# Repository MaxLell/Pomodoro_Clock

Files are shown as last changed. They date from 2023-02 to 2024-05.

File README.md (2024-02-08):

# Pomodoro_Clock

## Why?
This device forces me to take breaks in regular intervals throughout the day. Research has shown that the brain grows tired when being forced to focus on tasks on a prolonged time. (I think everybody can also observe this in his own life). But research also shows, that if you take regular breaks, you do not deplete your mental ressources as quickly and you can focus for longer hours.

So this is basically what this device (will) is about. It will sit on my desk and ping me, when I need to take a break, and not only ping me, but rather shine a bright light at me, so that I actually get my lazy a** up and move around for a couple of minutes - day in day out. 
You might say: Well you can also set a timer on your smartphone and go from there, to which I reply: Yeah you can, but if you want to do that day-in, day-out, you need a lot of will power and the most perfect habits the world has ever witnessed in man-kind. I am not such a person. 

And for this reason I built this device.

## What?
So what is this marvelous device I am talking about? Well I am glad you are asking: It is basically a box of lights, where you can set up the interval for which you want to work (the next cycle is composed of Worktime and Breaktime). Then it will run a countdown timer.

## How?
- This project is partially also a way for myself to learn and work on a complicated challenge: I already resolved the architecture of this multi-module Architecture (using a Message Broker, so that these modules only exchange data via this Messages-Interface - Observer Pattern). Or working on the implementation of high-speed low level peripherals, which require the usage of the DMA.

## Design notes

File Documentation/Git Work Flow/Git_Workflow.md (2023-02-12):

# Git Workflow
## Applicability
This Workflow is to be applied on the
- FW / SW Development
- Electronics Design

## Branch Descriptions
- **Main Branch**: These are the Releases that represent a working sample for the user

- **Develop Branch**: This is where the regular development takes place

- **Feature Branch**: In this branch the individual features are implemented

- **Spike Branch**: This is where experiments are held. The code that is built here is not necessarily merged back to the development branch. These are just exploratory features that might be considered in the future

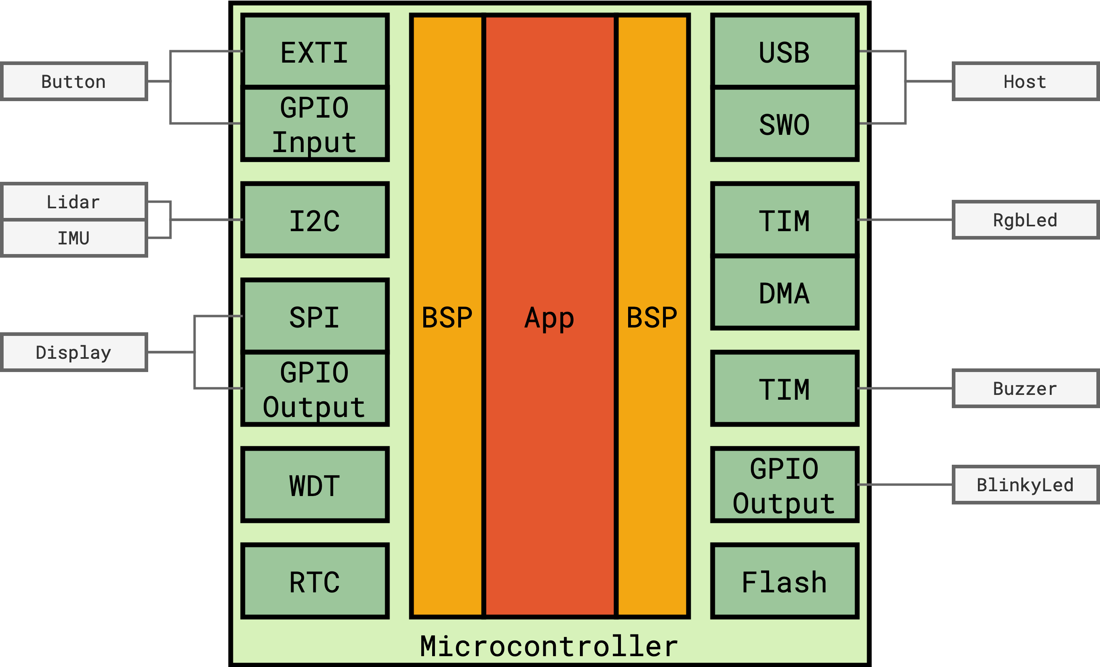
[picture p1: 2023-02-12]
Documentation/Architecture/Firmware/Pomodoro Microcontroller Block Diagram.drawio.png

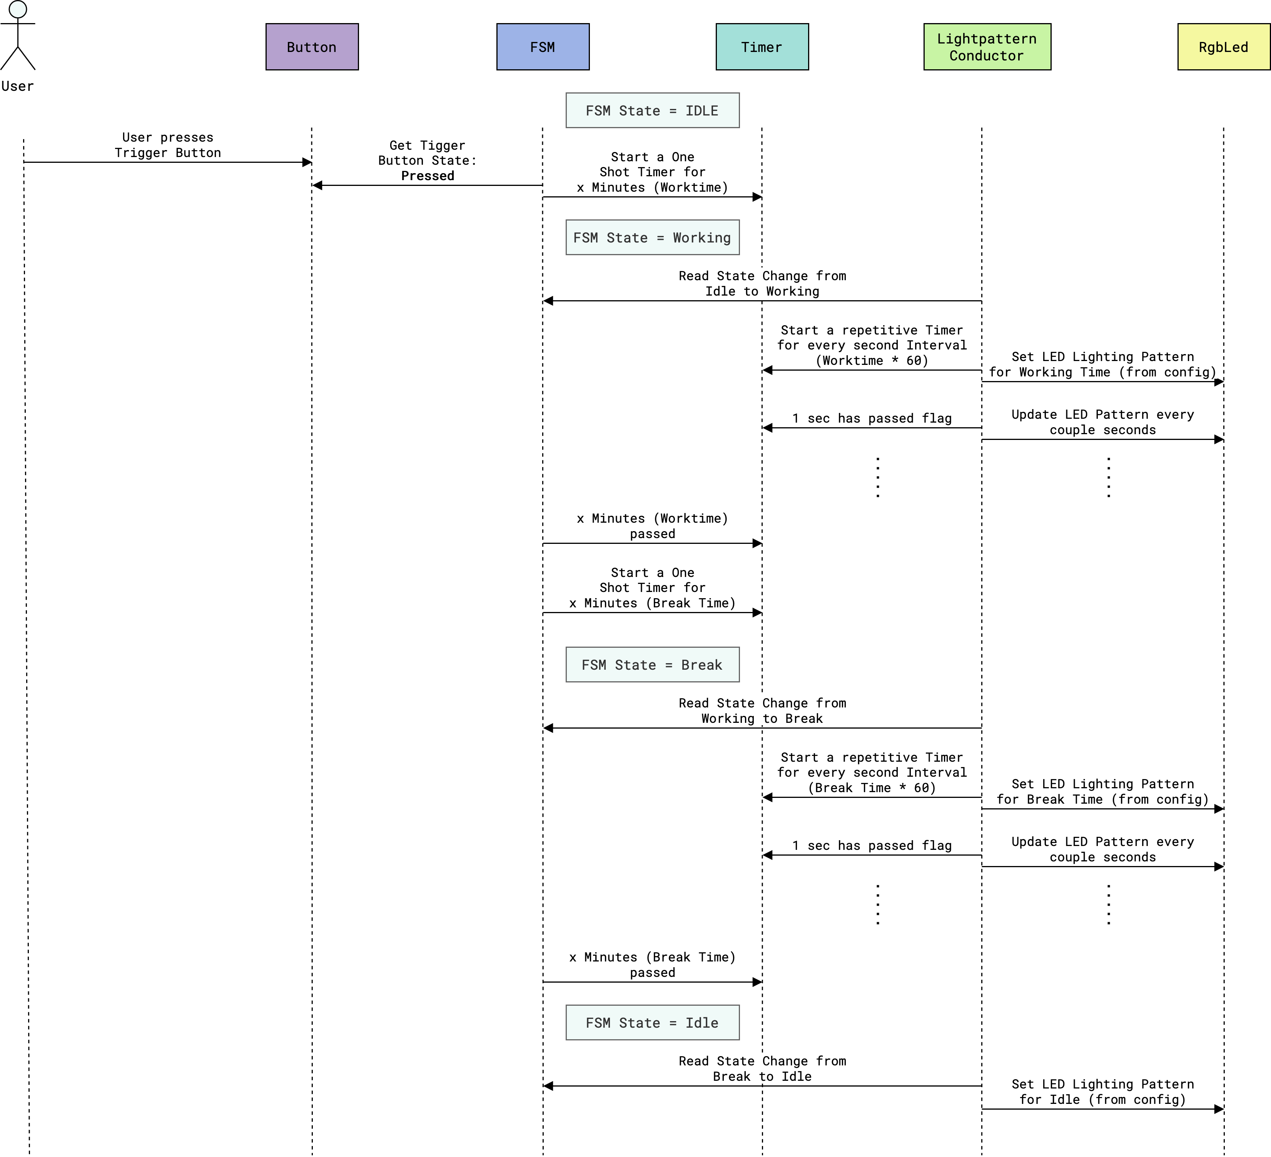
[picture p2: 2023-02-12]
Documentation/Architecture/Firmware/Pomodoro-Context-Diagram_User-presses-button-Nominal.drawio(2).png

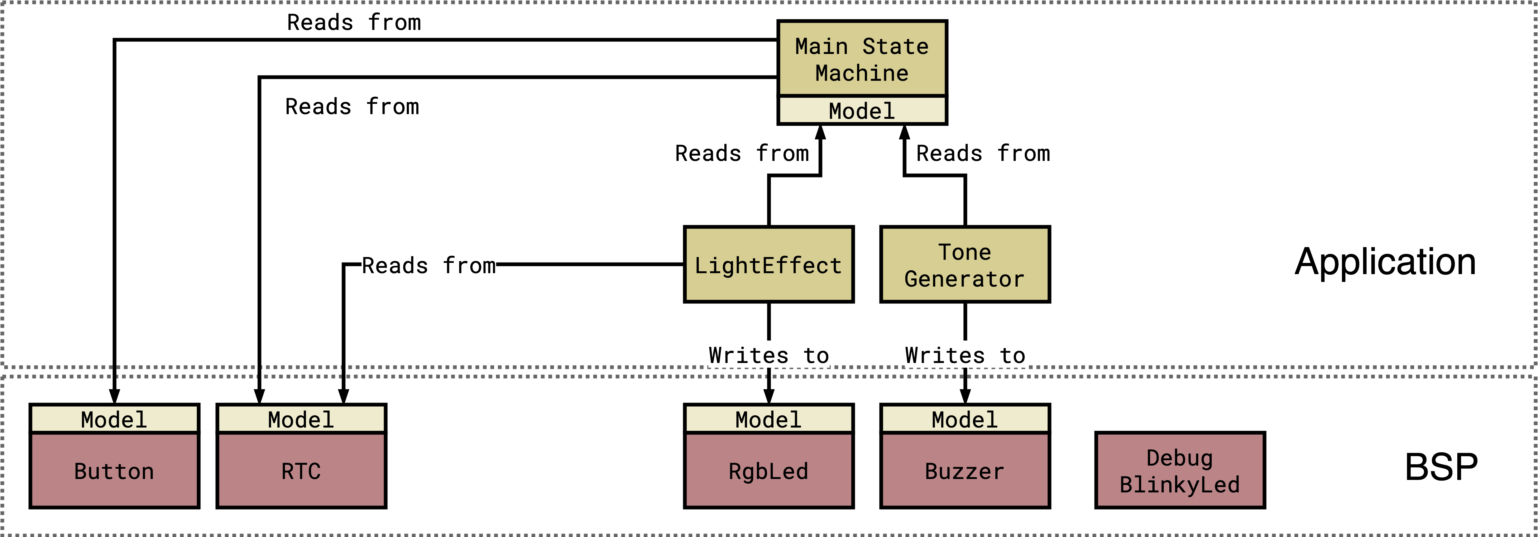
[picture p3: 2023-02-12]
Documentation/Architecture/Firmware/Pomodoro Layered Architecture.drawio(1).drawio.png

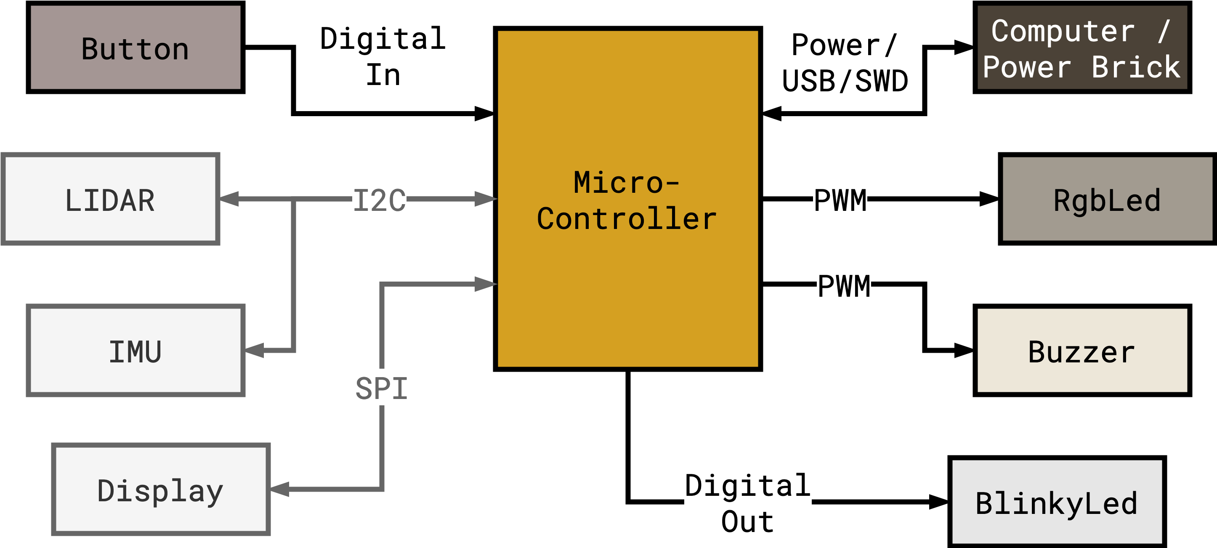
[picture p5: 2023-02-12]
Documentation/Architecture/Pomodoro System Diagram.drawio(2).png

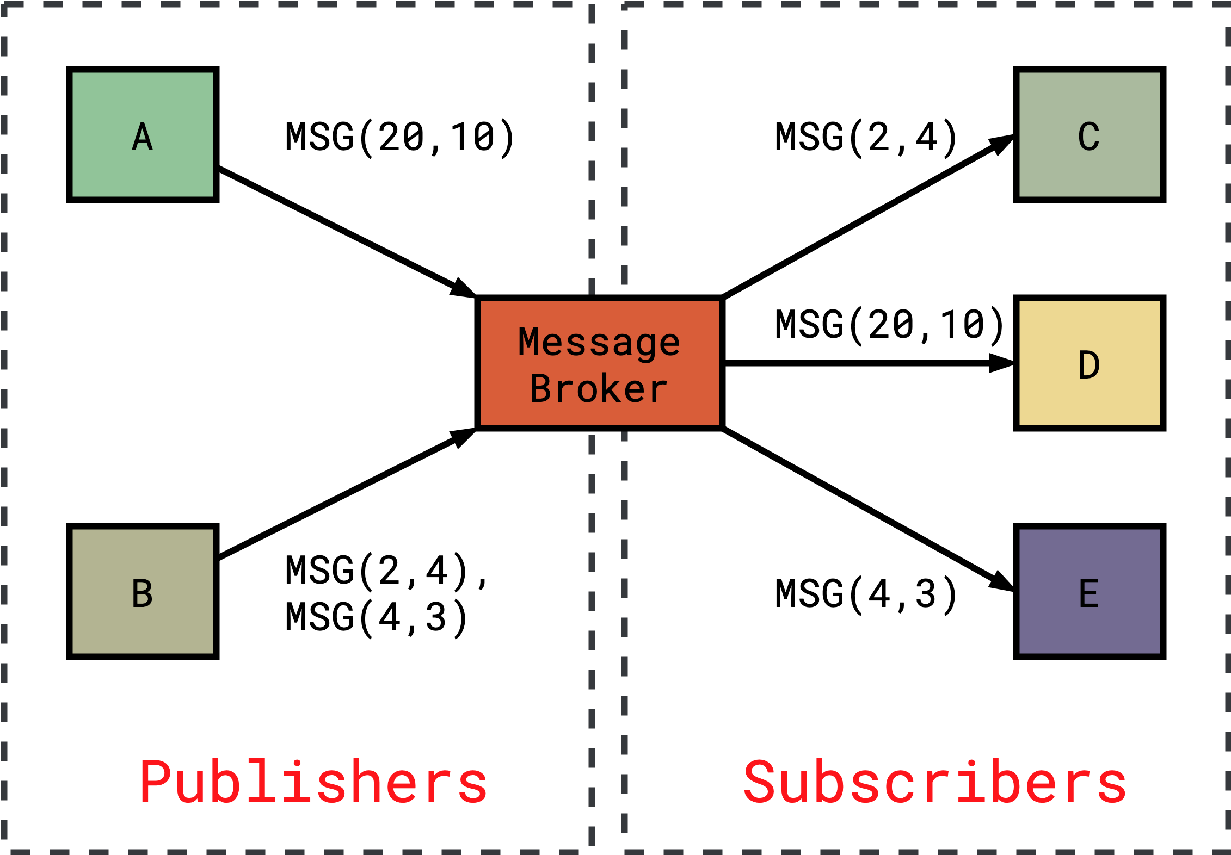
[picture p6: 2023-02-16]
Documentation/Architecture/Firmware/MessageBroker_Spike.drawio.png

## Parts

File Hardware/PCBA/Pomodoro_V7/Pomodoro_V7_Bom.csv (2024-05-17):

Reference | Qty | Value | Mfg Part # | Datasheet | Footprint | DNP
C1,C5,C8,C9 | 4 | 1u/16V+/X5R |  | ~ | Capacitor_SMD:C_0805_2012Metric
C2,C3 | 2 | 10u/16V+/X5R |  | ~ | Capacitor_SMD:C_0805_2012Metric
C4,C6,C7 | 3 | 100n/16V+/X5R |  | ~ | Capacitor_SMD:C_0805_2012Metric
J11 | 1 | USB4120-03-C_REVA | USB4120-03-C | https://mm.digikey.com/Volume0/opasdata/d220001/medias/docus/5564/USB4120%20-%20USB%202.0%20Connector%20Type%20C%20Vertical%20Receptacle.pdf | Connector:GCT_USB4120-03-C_REVA
J10 | 1 | Conn_01x02_Pin |  | ~ | Connector_PinHeader_2.54mm:PinHeader_1x02_P2.54mm_Horizontal
U2 | 1 | USBLC6-2SC6 | USBLC6-2SC6 |  | Diode_SMD:SOT95P280X145-6N
D1,D2,D3,D4,D5,D6,D7,D8,D9,D10,D11,D12,D13,D14,D15,D16,D17,D18,D19,D20,D21,D22,D23,D24,D25,D26,D27,D28,D29,D30,D31,D32,D33,D34,D35,D36,D37,D38,D39,D40,D41,D42,D43,D44,D45,D46,D47,D48,D49,D50,D51,D52,D53,D54,D55,D56,D57,D58,D59,D60 | 60 | WS2812B-2020 |  | https://cdn-shop.adafruit.com/product-files/4684/4684_WS2812B-2020_V1.3_EN.pdf | LED_SMD:LED_WS2812B-2020_PLCC4_2.0x2.0mm
U1 | 1 | LIS2HH12 | LIS2HH12TR | www.st.com/resource/en/datasheet/lis2hh12.pdf | Package_LGA:Kionix_LGA-12_2x2mm_P0.5mm_LayoutBorder2x4y
U3 | 1 | AP2112K-3.3 | AP2112K-3.3TRG1 | https://www.diodes.com/assets/Datasheets/AP2112.pdf | Package_TO_SOT_SMD:SOT-23-5
R6 | 1 | 10k 1/20W | PTV09A-4025F-B103 | https://eu.mouser.com/datasheet/2/54/ptv09-777818.pdf | Potentiometer_THT:Pot
R1 | 1 | 10k(1%) |  | ~ | Resistor_SMD:R_0805_2012Metric
R2,R3,R4,R5,R7,R8,R9,R10 | 8 | 5k1(1%) |  | ~ | Resistor_SMD:R_0805_2012Metric
R11 | 1 | 100R(1%) |  | ~ | Resistor_SMD:R_0805_2012Metric
IC1 | 1 | ESP32-S2-MINI-2-N4 | ESP32-S2-MINI-2-N4 | https://www.espressif.com/sites/default/files/documentation/esp32-s2-mini-2_esp32-s2-mini-2u_datasheet_en.pdf | RF_Module:ESP32-S2-MINI-1

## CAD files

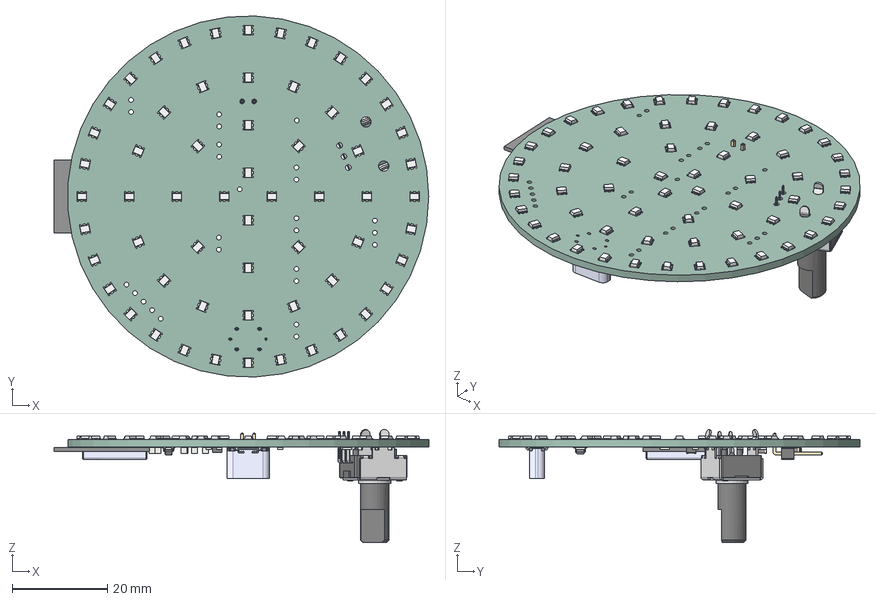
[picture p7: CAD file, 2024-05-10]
Hardware/PCBA/Pomodoro_V7/Pomodoro_V7.step
78.8 x 75.9 x 23.8 mm
WS2812-2020 x 60
R_0805_2012Metric x 10
ESP32-S2-MINI-1
SOT_23_5
USBLC6-2SC6Y
C_0805_2012Metric x 9
USB4120-03-C
LGA_12_2x2mm_P05mm
R-0904N
PinHeader_1x02_P254mm_Horizontal
_autosave-Pomodoro_V7_PCB

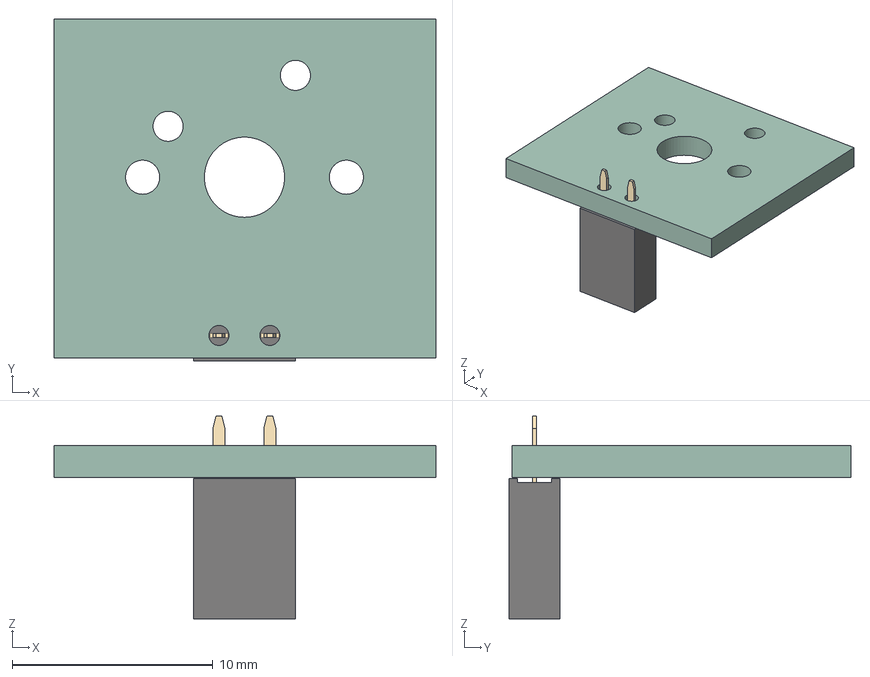
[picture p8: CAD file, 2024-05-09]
Hardware/PCBA/Pomodoro_V7_TriggerButton/Pomodoro_V7_TriggerButton.step
19.1 x 17.0 x 10.1 mm
PinSocket_1x02_P254mm_Vertical
Pomodoro_V7_TriggerButton_PCB

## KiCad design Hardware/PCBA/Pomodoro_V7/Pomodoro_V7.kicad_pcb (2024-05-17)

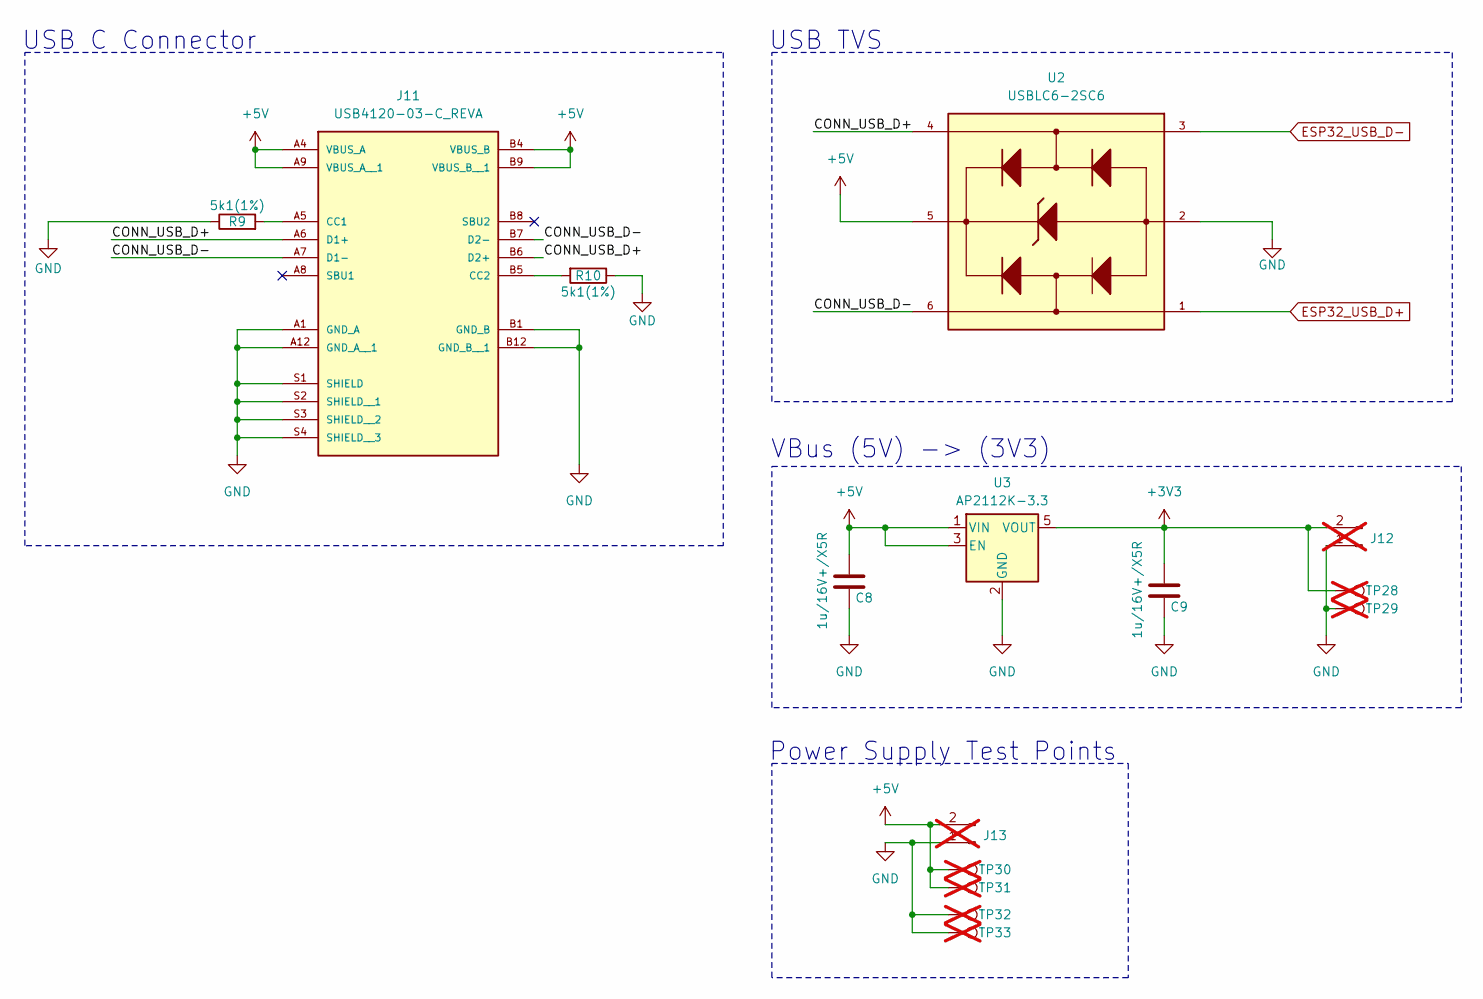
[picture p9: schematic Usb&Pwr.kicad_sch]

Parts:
C8, C9: 1u/16V+/X5R; C_0805_2012Metric
J11: USB4120-03-C_REVA; GCT_USB4120-03-C_REVA; PARTREV A
J12, J13: Conn_01x02_Pin; PinHeader_1x02_P2.54mm_Vertical; not fitted
R9, R10: 5k1(1%); R_0805_2012Metric; Part ID CR0805-FX-5101ELF
TP28, TP29, TP30, TP31, TP32, TP33: TestPoint; TestPoint_Pad_D1.0mm; not fitted
U2: USBLC6-2SC6; SOT95P280X145-6N; Mfg Part # USBLC6-2SC6
U3: AP2112K-3.3; SOT-23-5; Mfg Part # AP2112K-3.3TRG1

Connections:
+3V3: C9.1, J12.2, TP28.1, U3.5 (VOUT); also elsewhere on the board
+5V: C8.1, J11.A4 (VBUS_A), J11.A9 (VBUS_A__1), J11.B4 (VBUS_B), J11.B9 (VBUS_B__1), J13.2, TP30.1, TP31.1, U2.5, U3.1 (VIN), U3.3 (EN); also elsewhere on the board
/USB Conn and PWR /CONN_USB_D+: J11.A6 (D1+), J11.B6 (D2+), U2.4
/USB Conn and PWR /CONN_USB_D-: J11.A7 (D1-), J11.B7 (D2-), U2.6
ESP32_USB_D+: U2.1; also elsewhere on the board
ESP32_USB_D-: U2.3; also elsewhere on the board
GND: C8.2, C9.2, J11.A1 (GND_A), J11.A12 (GND_A__1), J11.B1 (GND_B), J11.B12 (GND_B__1), J11.S1 (SHIELD), J11.S2 (SHIELD__1), J11.S3 (SHIELD__2), J11.S4 (SHIELD__3), J12.1, J13.1, R9.1, R10.1, TP29.1, TP32.1, TP33.1, U2.2, U3.2 (GND); also elsewhere on the board
unnamed: J11.A5 (CC1), R9.2
unnamed: J11.B5 (CC2), R10.2

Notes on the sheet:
USB TVS
Power Supply Test Points
VBus (5V) -> (3V3)
USB C Connector

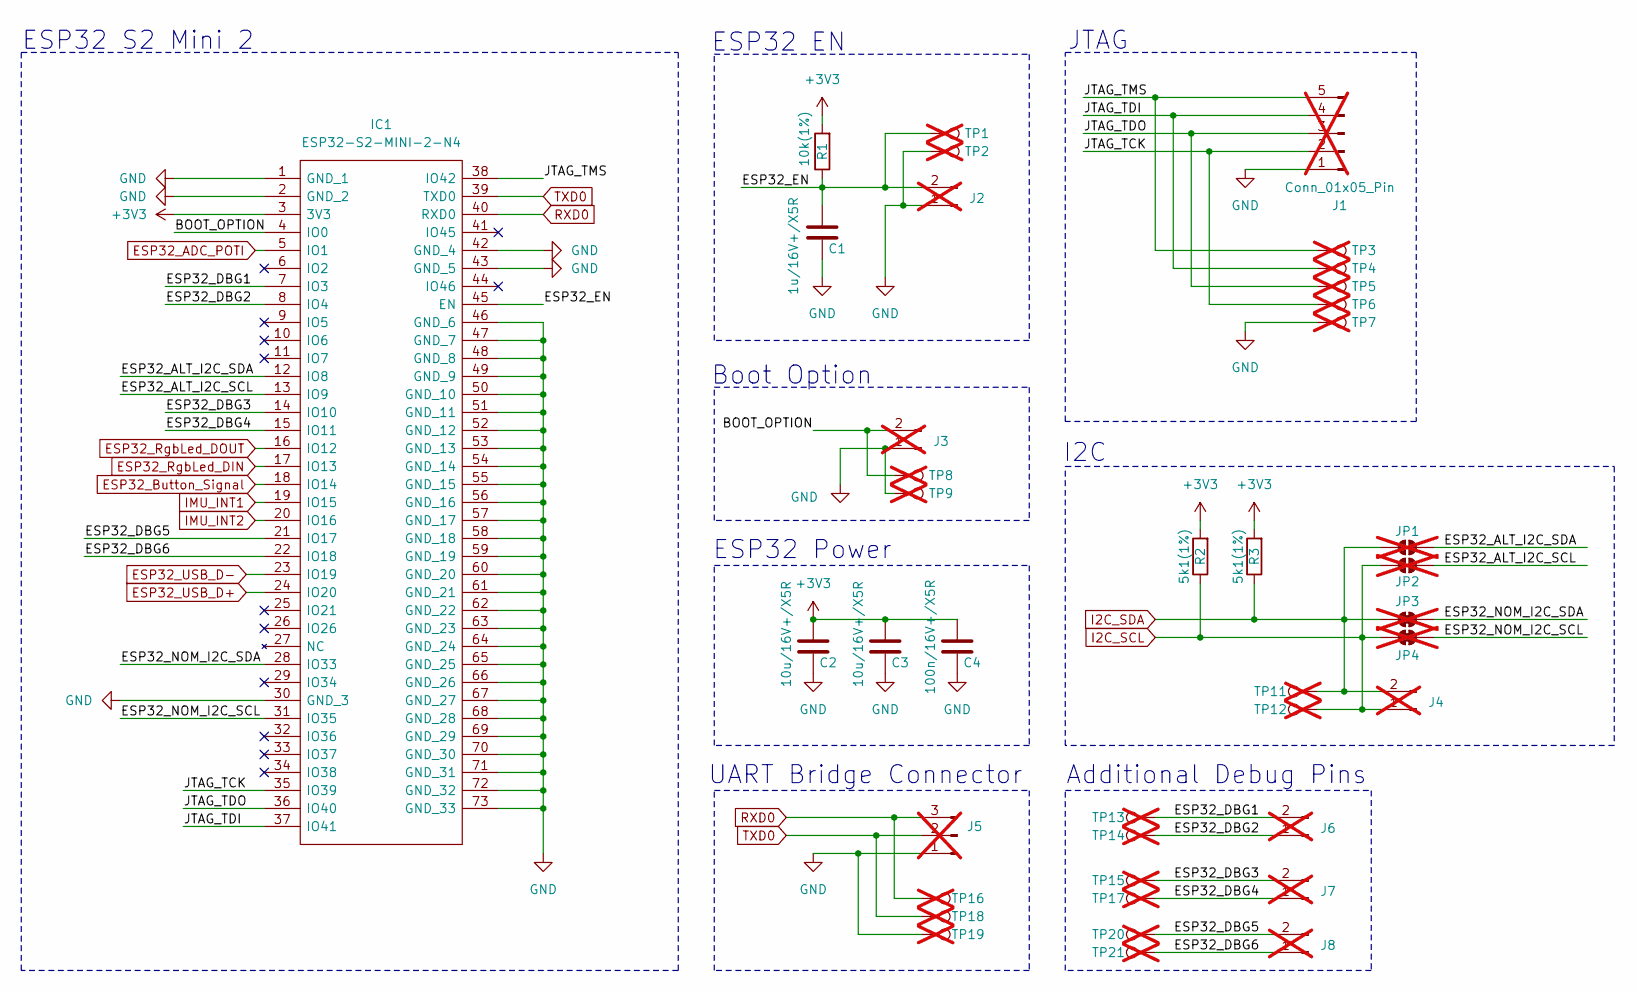
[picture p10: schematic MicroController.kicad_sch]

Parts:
C1: 1u/16V+/X5R; C_0805_2012Metric
C2, C3: 10u/16V+/X5R; C_0805_2012Metric
C4: 100n/16V+/X5R; C_0805_2012Metric
IC1: ESP32-S2-MINI-2-N4; ESP32-S2-MINI-1; Mouser Part Number 356-ESP32MINI-2-N4
J1: Conn_01x05_Pin; PinHeader_1x05_P2.54mm_Vertical; not fitted
J2, J3, J4, J6, J7, J8: Conn_01x02_Pin; PinHeader_1x02_P2.54mm_Vertical; not fitted
J5: Conn_01x03_Pin; PinHeader_1x03_P2.54mm_Vertical; not fitted
JP1, JP2: SolderJumper_2_Open; SolderJumper-2_P1.3mm_Open_RoundedPad1.0x1.5mm; not fitted
JP3, JP4: SolderJumper_2_Bridged; SolderJumper-2_P1.3mm_Bridged2Bar_RoundedPad1.0x1.5mm; not fitted
R1: 10k(1%); R_0805_2012Metric; Part ID CR0805-FX-5101ELF
R2, R3: 5k1(1%); R_0805_2012Metric; Part ID CR0805-FX-5101ELF
TP1, TP2, TP3, TP4, TP5, TP6, TP7, TP8, TP9, TP11, TP12, TP13, TP14, TP15, TP16, TP17, TP18, TP19, TP20, TP21: TestPoint; TestPoint_Pad_D1.0mm; not fitted

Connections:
+3V3: C2.1, C3.1, C4.1, IC1.3 (3V3), R1.2, R2.2, R3.2; also elsewhere on the board
/MicroController/BOOT_OPTION: IC1.4 (IO0), J3.2, TP8.1
/MicroController/ESP32_ALT_I2C_SCL: IC1.13 (IO9), JP2.1 (A)
/MicroController/ESP32_ALT_I2C_SDA: IC1.12 (IO8), JP1.2 (B)
/MicroController/ESP32_DBG1: IC1.7 (IO3), J6.2, TP13.1
/MicroController/ESP32_DBG2: IC1.8 (IO4), J6.1, TP14.1
/MicroController/ESP32_DBG3: IC1.14 (IO10), J7.2, TP15.1
/MicroController/ESP32_DBG4: IC1.15 (IO11), J7.1, TP17.1
/MicroController/ESP32_DBG5: IC1.21 (IO17), J8.2, TP20.1
/MicroController/ESP32_DBG6: IC1.22 (IO18), J8.1, TP21.1
/MicroController/ESP32_EN: C1.1, IC1.45 (EN), J2.2, R1.1, TP1.1
/MicroController/ESP32_NOM_I2C_SCL: IC1.31 (IO35), JP4.1 (A)
/MicroController/ESP32_NOM_I2C_SDA: IC1.28 (IO33), JP3.2 (B)
/MicroController/JTAG_TCK: IC1.35 (IO39), J1.2, TP6.1
/MicroController/JTAG_TDI: IC1.37 (IO41), J1.4, TP4.1
/MicroController/JTAG_TDO: IC1.36 (IO40), J1.3, TP5.1
/MicroController/JTAG_TMS: IC1.38 (IO42), J1.5, TP3.1
ESP32_ADC_POTI: IC1.5 (IO1); also elsewhere on the board
ESP32_Button_Signal: IC1.18 (IO14); also elsewhere on the board
ESP32_RgbLed_DIN: IC1.17 (IO13); also elsewhere on the board
ESP32_RgbLed_DOUT: IC1.16 (IO12); also elsewhere on the board
ESP32_USB_D+: IC1.24 (IO20); also elsewhere on the board
ESP32_USB_D-: IC1.23 (IO19); also elsewhere on the board
GND: C1.2, C2.2, C3.2, C4.2, IC1.1 (GND_1), IC1.2 (GND_2), IC1.30 (GND_3), IC1.42 (GND_4), IC1.43 (GND_5), IC1.46 (GND_6), IC1.47 (GND_7), IC1.48 (GND_8), IC1.49 (GND_9), IC1.50 (GND_10), IC1.51 (GND_11), IC1.52 (GND_12), IC1.53 (GND_13), IC1.54 (GND_14), IC1.55 (GND_15), IC1.56 (GND_16), IC1.57 (GND_17), IC1.58 (GND_18), IC1.59 (GND_19), IC1.60 (GND_20), IC1.61 (GND_21), IC1.62 (GND_22), IC1.63 (GND_23), IC1.64 (GND_24), IC1.65 (GND_25), IC1.66 (GND_26), IC1.67 (GND_27), IC1.68 (GND_28), IC1.69 (GND_29), IC1.70 (GND_30), IC1.71 (GND_31), IC1.72 (GND_32), IC1.73 (GND_33), J1.1, J2.1, J3.1, J5.1, TP2.1, TP7.1, TP9.1, TP19.1; also elsewhere on the board
I2C_SCL: J4.1, JP2.2 (B), JP4.2 (B), R2.1, TP12.1; also elsewhere on the board
I2C_SDA: J4.2, JP1.1 (A), JP3.1 (A), R3.1, TP11.1; also elsewhere on the board
IMU_INT1: IC1.19 (IO15); also elsewhere on the board
IMU_INT2: IC1.20 (IO16); also elsewhere on the board
RXD0: IC1.40 (RXD0), J5.3, TP16.1
TXD0: IC1.39 (TXD0), J5.2, TP18.1

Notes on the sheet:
ESP32 Power
ESP32 EN
Additional Debug Pins
ESP32 S2 Mini 2
UART Bridge Connector
JTAG
I2C
Boot Option

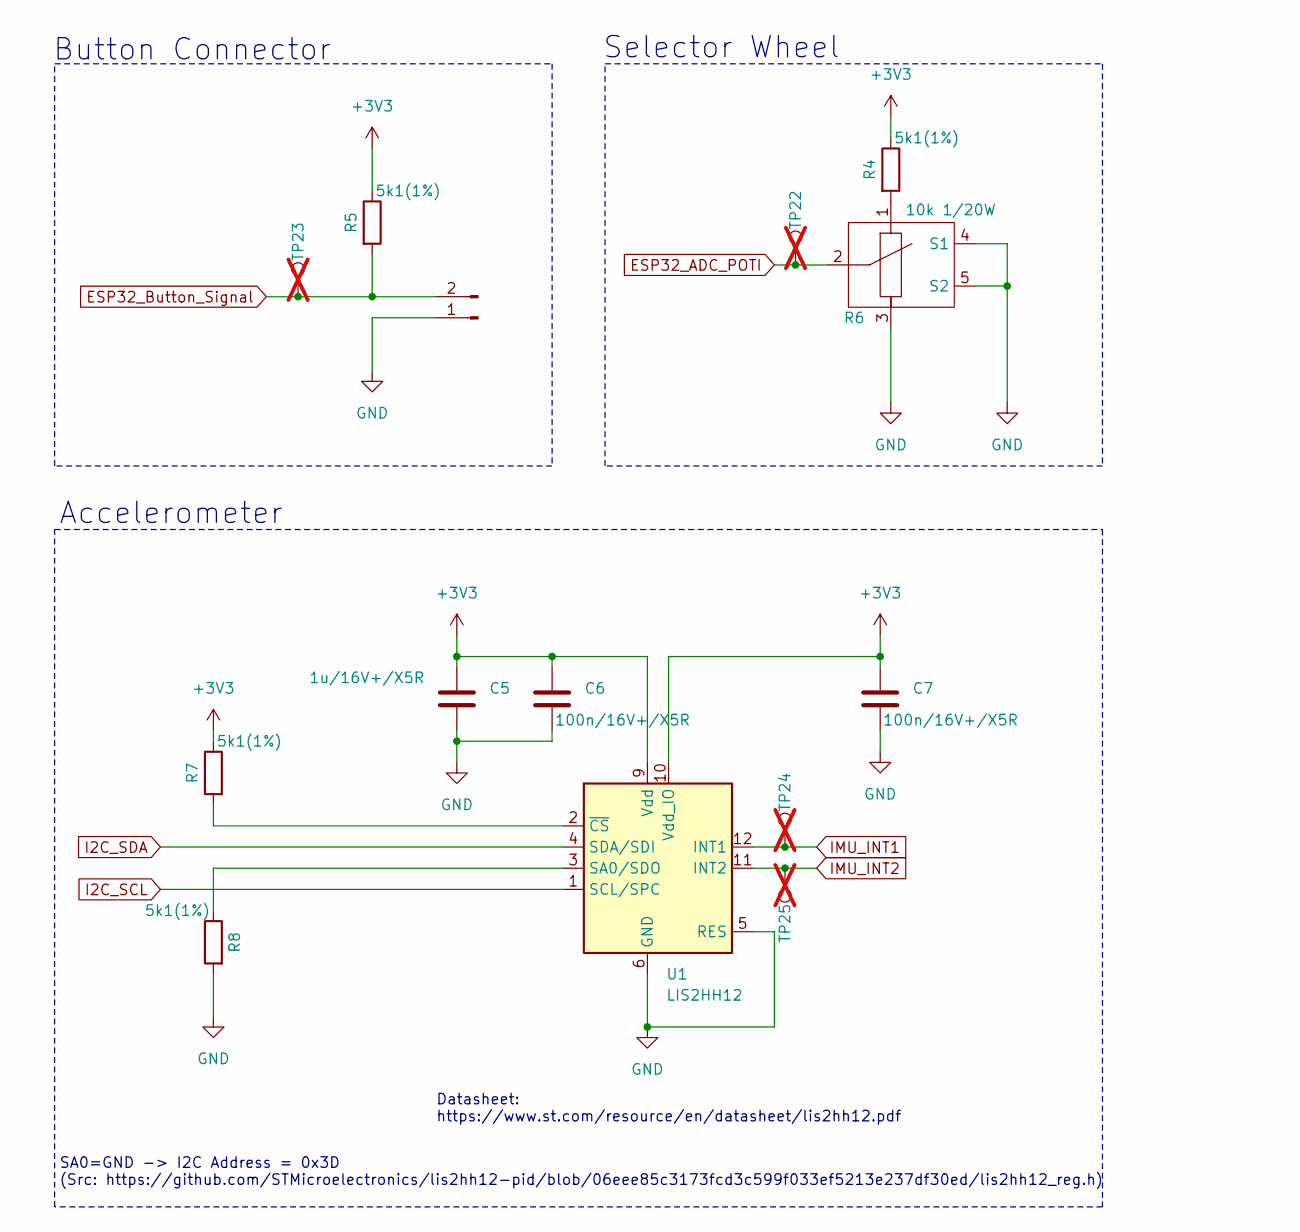
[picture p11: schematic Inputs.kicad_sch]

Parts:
C5: 1u/16V+/X5R; C_0805_2012Metric; MPN 0805B105K250DC
C6, C7: 100n/16V+/X5R; C_0805_2012Metric; MPN CC0805KRX7R9BB104
J10: Conn_01x02_Pin; PinHeader_1x02_P2.54mm_Horizontal
R4, R5, R7, R8: 5k1(1%); R_0805_2012Metric; Part ID CR0805-FX-5101ELF
R6: 10k 1/20W; Pot; Mfg Part # PTV09A-4025F-B103
TP22, TP23, TP24, TP25: TestPoint; TestPoint_Pad_D1.0mm; not fitted
U1: LIS2HH12; Kionix_LGA-12_2x2mm_P0.5mm_LayoutBorder2x4y; MPN LIS2HH12

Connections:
+3V3: C5.2, C6.2, C7.2, R4.1, R5.1, R7.1, U1.9 (Vdd), U1.10 (Vdd_IO); also elsewhere on the board
ESP32_ADC_POTI: R6.2, TP22.1; also elsewhere on the board
ESP32_Button_Signal: J10.2, R5.2, TP23.1; also elsewhere on the board
GND: C5.1, C6.1, C7.1, J10.1, R6.3, R6.4 (S1), R6.5 (S2), R8.2, U1.5 (RES), U1.6 (GND), U1.7 (GND), U1.8 (GND); also elsewhere on the board
I2C_SCL: U1.1 (SCL/SPC); also elsewhere on the board
I2C_SDA: U1.4 (SDA/SDI); also elsewhere on the board
IMU_INT1: TP24.1, U1.12 (INT1); also elsewhere on the board
IMU_INT2: TP25.1, U1.11 (INT2); also elsewhere on the board
unnamed: R4.2, R6.1
unnamed: R8.1, U1.3 (SA0/SDO)
unnamed: R7.2, U1.2 (~CS)

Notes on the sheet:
Accelerometer
SA0=GND -> I2C Address = 0x3D (Src: https://github.com/STMicroelectronics/lis2hh12-pid/blob/06eee85c3173fcd3c599f033ef5213e237df30ed/lis2hh12_reg.h)
Button Connector
Datasheet: https://www.st.com/resource/en/datasheet/lis2hh12.pdf
Selector Wheel

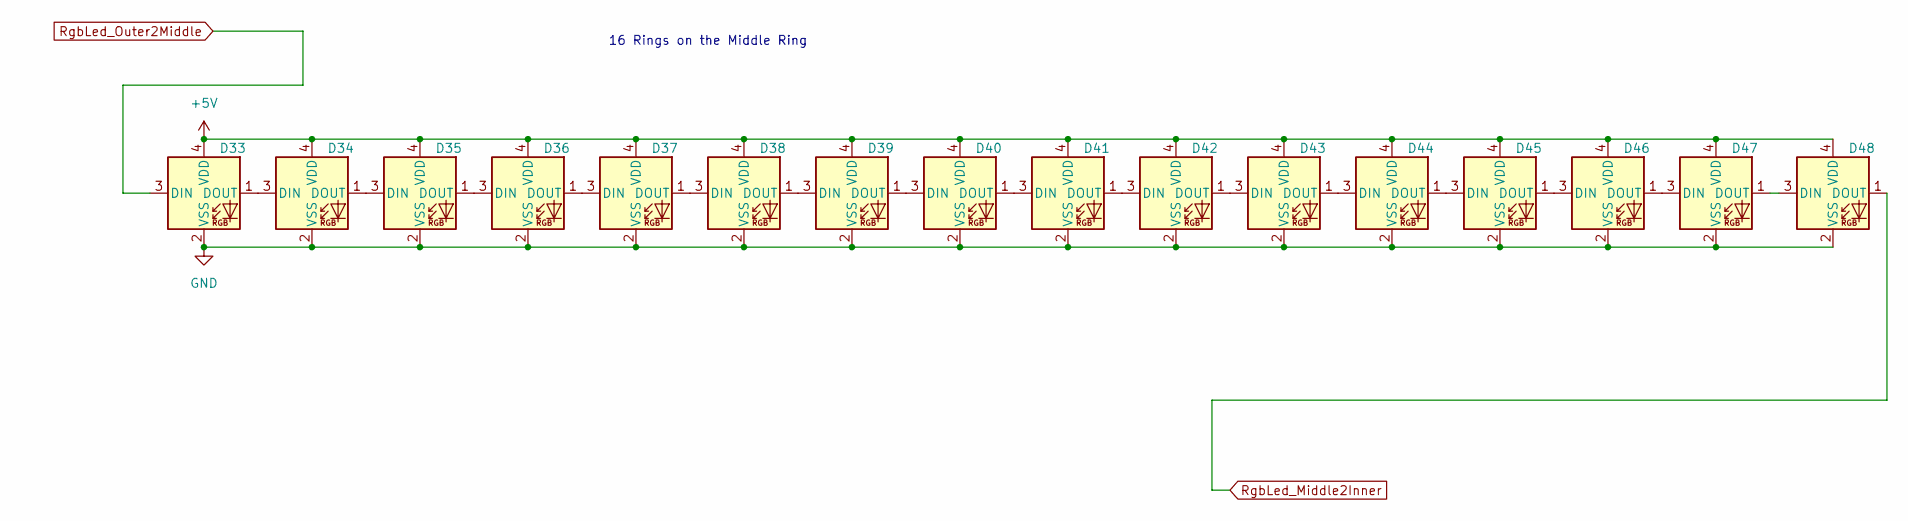
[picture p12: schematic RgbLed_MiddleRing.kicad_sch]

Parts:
D33, D34, D35, D36, D37, D38, D39, D40, D41, D42, D43, D44, D45, D46, D47, D48: WS2812B-2020; LED_WS2812B-2020_PLCC4_2.0x2.0mm; MPN WS2812B-2020

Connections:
+5V: D33.4 (VDD), D34.4 (VDD), D35.4 (VDD), D36.4 (VDD), D37.4 (VDD), D38.4 (VDD), D39.4 (VDD), D40.4 (VDD), D41.4 (VDD), D42.4 (VDD), D43.4 (VDD), D44.4 (VDD), D45.4 (VDD), D46.4 (VDD), D47.4 (VDD), D48.4 (VDD); also elsewhere on the board
GND: D33.2 (VSS), D34.2 (VSS), D35.2 (VSS), D36.2 (VSS), D37.2 (VSS), D38.2 (VSS), D39.2 (VSS), D40.2 (VSS), D41.2 (VSS), D42.2 (VSS), D43.2 (VSS), D44.2 (VSS), D45.2 (VSS), D46.2 (VSS), D47.2 (VSS), D48.2 (VSS); also elsewhere on the board
unnamed: D33.1 (DOUT), D34.3 (DIN)
unnamed: D34.1 (DOUT), D35.3 (DIN)
unnamed: D35.1 (DOUT), D36.3 (DIN)
unnamed: D36.1 (DOUT), D37.3 (DIN)
unnamed: D37.1 (DOUT), D38.3 (DIN)
unnamed: D38.1 (DOUT), D39.3 (DIN)
unnamed: D39.1 (DOUT), D40.3 (DIN)
unnamed: D40.1 (DOUT), D41.3 (DIN)
unnamed: D41.1 (DOUT), D42.3 (DIN)
unnamed: D42.1 (DOUT), D43.3 (DIN)
unnamed: D43.1 (DOUT), D44.3 (DIN)
unnamed: D44.1 (DOUT), D45.3 (DIN)
unnamed: D45.1 (DOUT), D46.3 (DIN)
unnamed: D46.1 (DOUT), D47.3 (DIN)
unnamed: D47.1 (DOUT), D48.3 (DIN)
RgbLed_Middle2Inner: D48.1 (DOUT); also elsewhere on the board
RgbLed_Outer2Middle: D33.3 (DIN); also elsewhere on the board

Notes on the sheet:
16 Rings on the Middle Ring

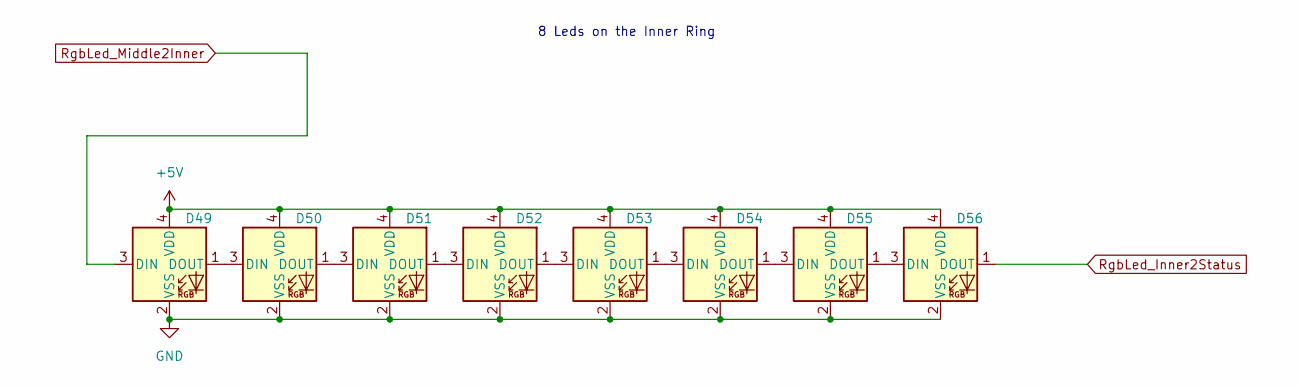
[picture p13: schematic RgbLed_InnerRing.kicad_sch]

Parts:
D49, D50, D51, D52, D53, D54, D55, D56: WS2812B-2020; LED_WS2812B-2020_PLCC4_2.0x2.0mm; MPN WS2812B-2020

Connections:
+5V: D49.4 (VDD), D50.4 (VDD), D51.4 (VDD), D52.4 (VDD), D53.4 (VDD), D54.4 (VDD), D55.4 (VDD), D56.4 (VDD); also elsewhere on the board
GND: D49.2 (VSS), D50.2 (VSS), D51.2 (VSS), D52.2 (VSS), D53.2 (VSS), D54.2 (VSS), D55.2 (VSS), D56.2 (VSS); also elsewhere on the board
unnamed: D49.1 (DOUT), D50.3 (DIN)
unnamed: D50.1 (DOUT), D51.3 (DIN)
unnamed: D51.1 (DOUT), D52.3 (DIN)
unnamed: D52.1 (DOUT), D53.3 (DIN)
unnamed: D53.1 (DOUT), D54.3 (DIN)
unnamed: D54.1 (DOUT), D55.3 (DIN)
unnamed: D55.1 (DOUT), D56.3 (DIN)
RgbLed_Inner2Status: D56.1 (DOUT); also elsewhere on the board
RgbLed_Middle2Inner: D49.3 (DIN); also elsewhere on the board

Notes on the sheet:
8 Leds on the Inner Ring

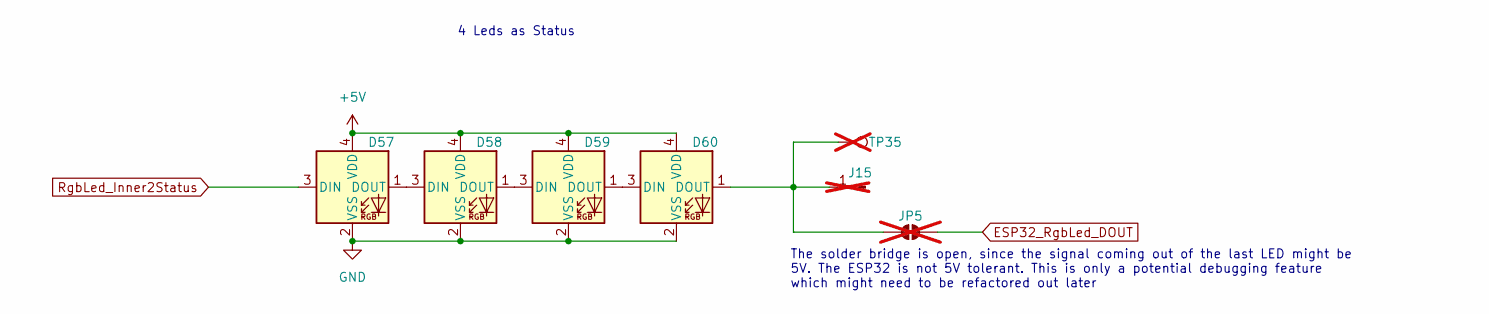
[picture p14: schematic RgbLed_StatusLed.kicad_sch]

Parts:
D57, D58, D59, D60: WS2812B-2020; LED_WS2812B-2020_PLCC4_2.0x2.0mm; MPN WS2812B-2020
J15: Conn_01x01_Pin; PinHeader_1x01_P2.54mm_Vertical; not fitted
JP5: SolderJumper_2_Open; SolderJumper-2_P1.3mm_Open_RoundedPad1.0x1.5mm; not fitted
TP35: TestPoint; TestPoint_Pad_D1.0mm; not fitted

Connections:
+5V: D57.4 (VDD), D58.4 (VDD), D59.4 (VDD), D60.4 (VDD); also elsewhere on the board
ESP32_RgbLed_DOUT: JP5.2 (B); also elsewhere on the board
GND: D57.2 (VSS), D58.2 (VSS), D59.2 (VSS), D60.2 (VSS); also elsewhere on the board
unnamed: D57.1 (DOUT), D58.3 (DIN)
unnamed: D58.1 (DOUT), D59.3 (DIN)
unnamed: D59.1 (DOUT), D60.3 (DIN)
unnamed: D60.1 (DOUT), J15.1, JP5.1 (A), TP35.1
RgbLed_Inner2Status: D57.3 (DIN); also elsewhere on the board

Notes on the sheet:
4 Leds as Status
The solder bridge is open, since the signal coming out of the last LED might be 5V. The ESP32 is not 5V tolerant. This is only a potential debugging feature which might need to be refactored out later

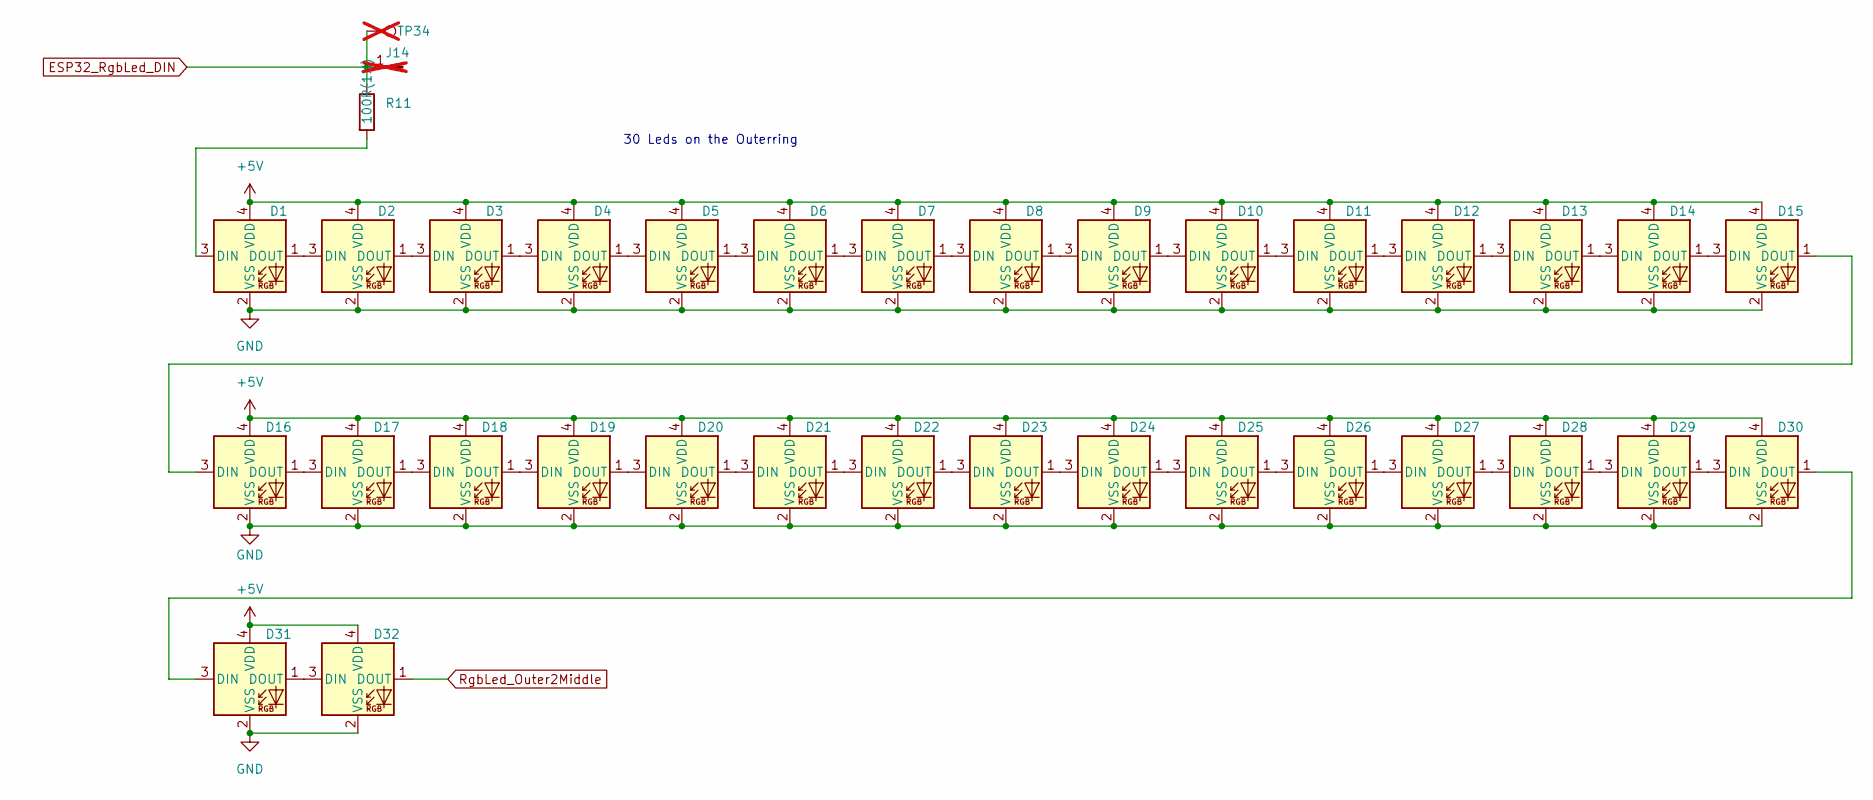
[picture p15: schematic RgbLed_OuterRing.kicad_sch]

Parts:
D1, D2, D3, D4, D5, D6, D7, D8, D9, D10, D11, D12, D13, D14, D15, D16, D17, D18, D19, D20, D21, D22, D23, D24, D25, D26, D27, D28, D29, D30, D31, D32: WS2812B-2020; LED_WS2812B-2020_PLCC4_2.0x2.0mm; MPN WS2812B-2020
J14: Conn_01x01_Pin; PinHeader_1x01_P2.54mm_Vertical; not fitted
R11: 100R(1%); R_0805_2012Metric; MPN RC0805FR-07100RL
TP34: TestPoint; TestPoint_Pad_D1.0mm; not fitted

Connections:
+5V: D1.4 (VDD), D2.4 (VDD), D3.4 (VDD), D4.4 (VDD), D5.4 (VDD), D6.4 (VDD), D7.4 (VDD), D8.4 (VDD), D9.4 (VDD), D10.4 (VDD), D11.4 (VDD), D12.4 (VDD), D13.4 (VDD), D14.4 (VDD), D15.4 (VDD), D16.4 (VDD), D17.4 (VDD), D18.4 (VDD), D19.4 (VDD), D20.4 (VDD), D21.4 (VDD), D22.4 (VDD), D23.4 (VDD), D24.4 (VDD), D25.4 (VDD), D26.4 (VDD), D27.4 (VDD), D28.4 (VDD), D29.4 (VDD), D30.4 (VDD), D31.4 (VDD), D32.4 (VDD); also elsewhere on the board
ESP32_RgbLed_DIN: J14.1, R11.1, TP34.1; also elsewhere on the board
GND: D1.2 (VSS), D2.2 (VSS), D3.2 (VSS), D4.2 (VSS), D5.2 (VSS), D6.2 (VSS), D7.2 (VSS), D8.2 (VSS), D9.2 (VSS), D10.2 (VSS), D11.2 (VSS), D12.2 (VSS), D13.2 (VSS), D14.2 (VSS), D15.2 (VSS), D16.2 (VSS), D17.2 (VSS), D18.2 (VSS), D19.2 (VSS), D20.2 (VSS), D21.2 (VSS), D22.2 (VSS), D23.2 (VSS), D24.2 (VSS), D25.2 (VSS), D26.2 (VSS), D27.2 (VSS), D28.2 (VSS), D29.2 (VSS), D30.2 (VSS), D31.2 (VSS), D32.2 (VSS); also elsewhere on the board
unnamed: D1.3 (DIN), R11.2
unnamed: D1.1 (DOUT), D2.3 (DIN)
unnamed: D2.1 (DOUT), D3.3 (DIN)
unnamed: D3.1 (DOUT), D4.3 (DIN)
unnamed: D4.1 (DOUT), D5.3 (DIN)
unnamed: D5.1 (DOUT), D6.3 (DIN)
unnamed: D6.1 (DOUT), D7.3 (DIN)
unnamed: D7.1 (DOUT), D8.3 (DIN)
unnamed: D8.1 (DOUT), D9.3 (DIN)
unnamed: D9.1 (DOUT), D10.3 (DIN)
unnamed: D10.1 (DOUT), D11.3 (DIN)
unnamed: D11.1 (DOUT), D12.3 (DIN)
unnamed: D12.1 (DOUT), D13.3 (DIN)
unnamed: D13.1 (DOUT), D14.3 (DIN)
unnamed: D14.1 (DOUT), D15.3 (DIN)
unnamed: D15.1 (DOUT), D16.3 (DIN)
unnamed: D16.1 (DOUT), D17.3 (DIN)
unnamed: D17.1 (DOUT), D18.3 (DIN)
unnamed: D18.1 (DOUT), D19.3 (DIN)
unnamed: D19.1 (DOUT), D20.3 (DIN)
unnamed: D20.1 (DOUT), D21.3 (DIN)
unnamed: D21.1 (DOUT), D22.3 (DIN)
unnamed: D22.1 (DOUT), D23.3 (DIN)
unnamed: D23.1 (DOUT), D24.3 (DIN)
unnamed: D24.1 (DOUT), D25.3 (DIN)
unnamed: D25.1 (DOUT), D26.3 (DIN)
unnamed: D26.1 (DOUT), D27.3 (DIN)
unnamed: D27.1 (DOUT), D28.3 (DIN)
unnamed: D28.1 (DOUT), D29.3 (DIN)
unnamed: D29.1 (DOUT), D30.3 (DIN)
unnamed: D30.1 (DOUT), D31.3 (DIN)
unnamed: D31.1 (DOUT), D32.3 (DIN)
RgbLed_Outer2Middle: D32.1 (DOUT); also elsewhere on the board

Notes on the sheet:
30 Leds on the Outerring

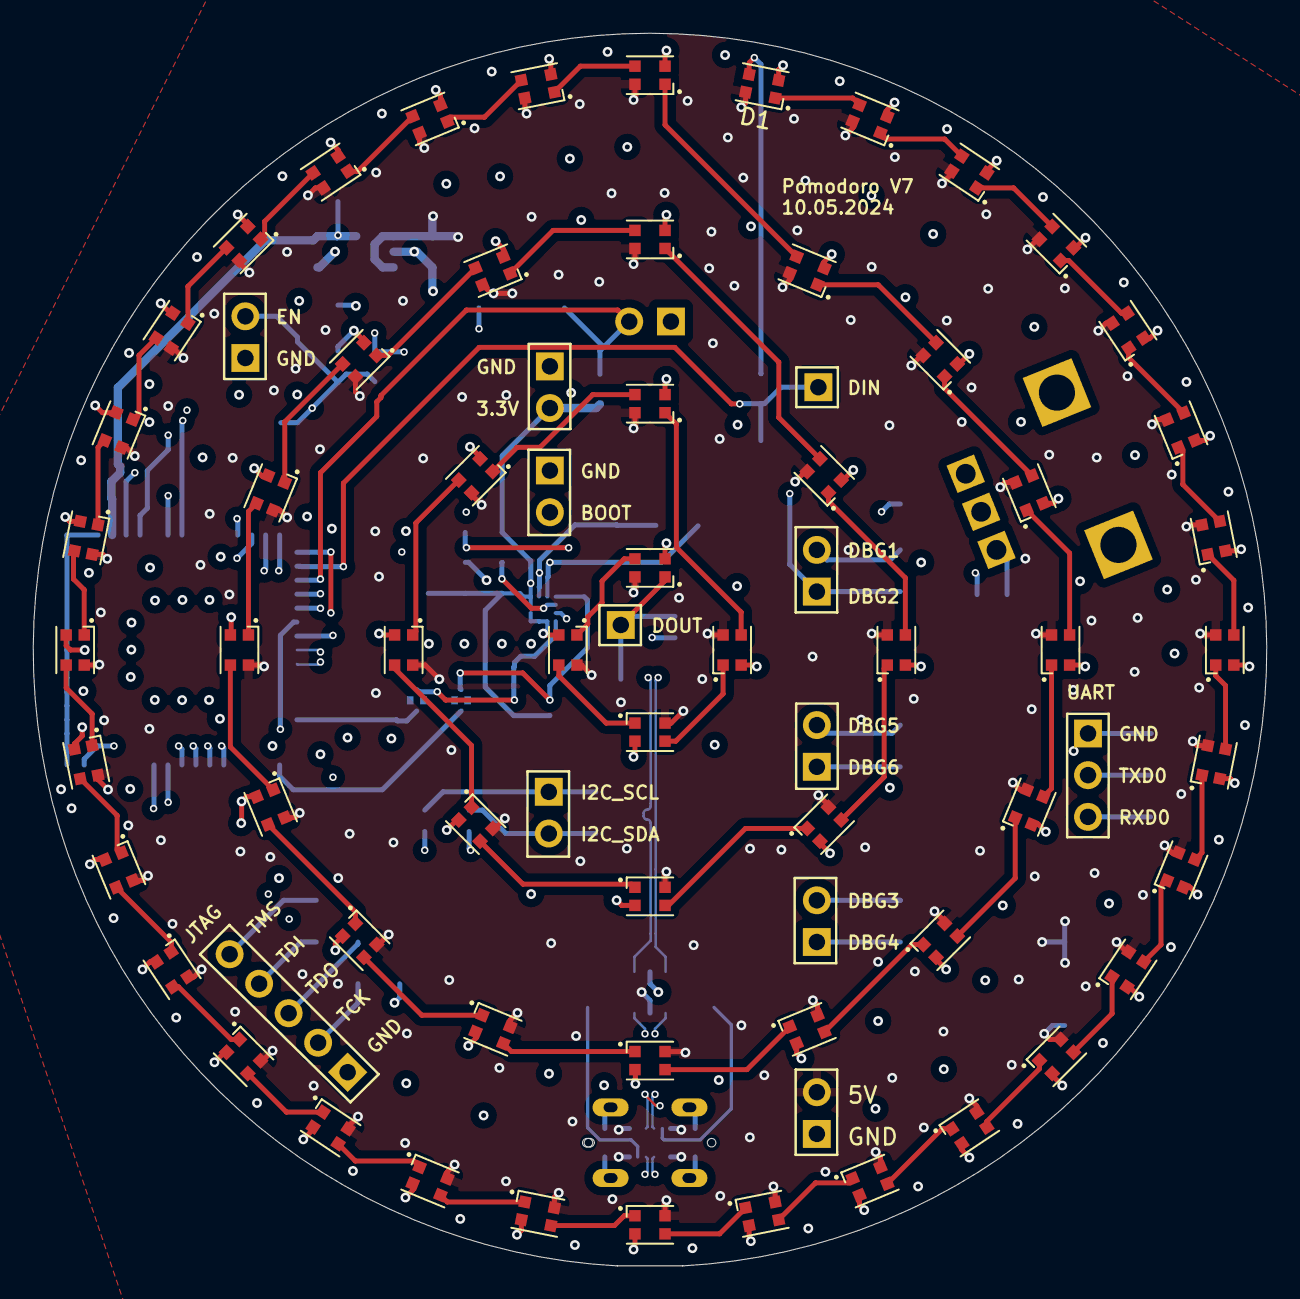
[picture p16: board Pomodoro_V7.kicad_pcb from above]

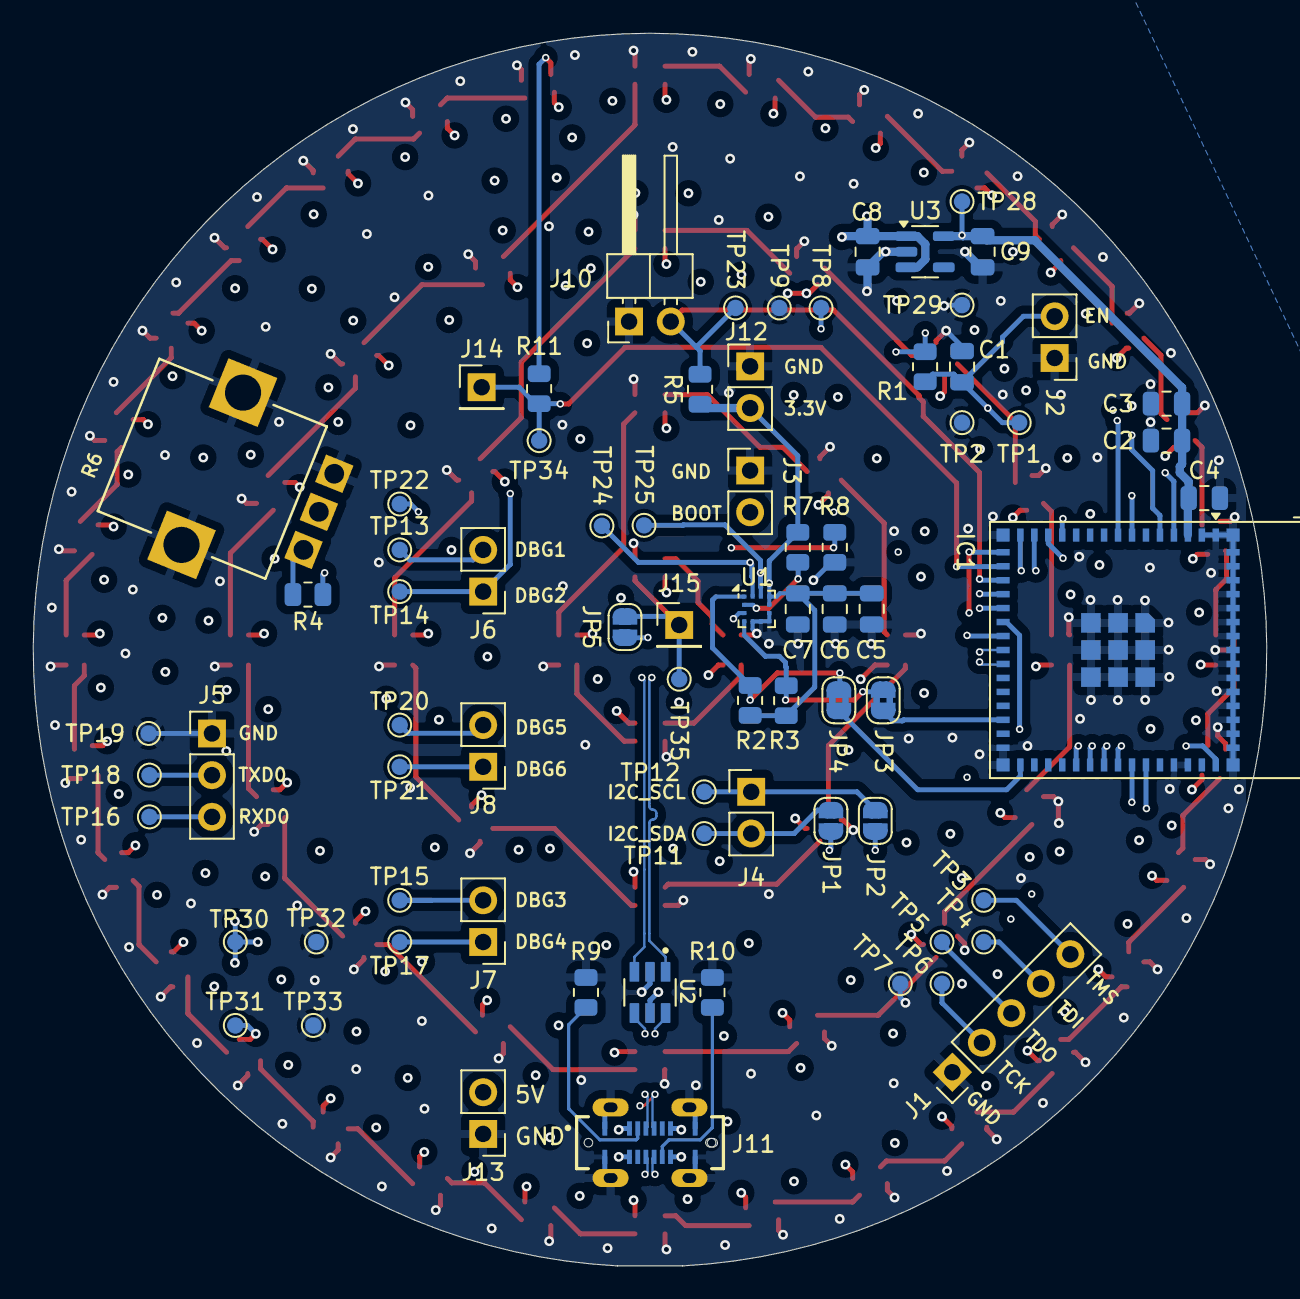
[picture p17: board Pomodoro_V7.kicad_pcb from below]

Board: 4 copper layers, 75.1 x 75.1 mm, 135 parts (75 on the bottom side), 99 nets.

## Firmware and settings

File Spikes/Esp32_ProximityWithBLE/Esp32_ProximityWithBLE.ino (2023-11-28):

#include <BLEAdvertisedDevice.h>
#include <BLEDevice.h>
#include <BLEScan.h>
#include <BLEAddress.h>

// #include "string.h"

/**
Source: https://youtu.be/azT2rosEo0k
*/

#define LED_PIN 19
#define CUT_OFF -40

void setup() {
  pinMode(LED_PIN, OUTPUT);
  BLEDevice::init("");

  Serial.begin(115200);
}

void loop() {
  BLEScan* scan = BLEDevice::getScan();
  scan->setActiveScan(true);
  BLEScanResults allBleDevices = scan->start(1);
  int bestReading = CUT_OFF;

  Serial.print("Number of BLE Devices nearby: ");
  Serial.println(allBleDevices.getCount());

  int maxSignalStrength = 100;
  for (int i = 0; i < allBleDevices.getCount(); i++) {
    BLEAdvertisedDevice device = allBleDevices.getDevice(i);

    // Serial.print("Names of Devices: ");
    // std::string name =  device.getName();
    // Serial.println(name.c_str());

    int rssi = device.getRSSI();

    if (maxSignalStrength > 0) {
      maxSignalStrength = rssi;
    } else {
      if (rssi > maxSignalStrength) {
        maxSignalStrength = rssi;
      }
    }
  }

  Serial.print("Best Signal: ");
  Serial.println(maxSignalStrength);

  digitalWrite(
    LED_PIN,
    maxSignalStrength > CUT_OFF ? HIGH : LOW
  );
  Serial.println("------------------------------------");
}

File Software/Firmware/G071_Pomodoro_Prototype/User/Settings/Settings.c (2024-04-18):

#include "Settings.h"
#include "Common.h"
#include "MessageBroker.h"
#include "MessageDefinitions.h"
#include "Delay.h"
#include "PomodoroControl_Datatypes.h"
#include "LightEffects.h"
#include "FSM.h"
#include "CfgStore_Datatypes.h"
#include "CountdownTimer.h"

typedef struct
{
    BOOL bCfgStoreRequested;
    BOOL bCfgCurrentSettingRequested;

    BOOL bCfgStoreReceived;
    BOOL bCfgCurrentSettingReceived;

    BOOL bRotaryEncoderButtonPressed;

} InternalState_t;

/********************************************************
 * Private Variables
 ********************************************************/

STATIC TimeCfg_s sTimeCfg[CFG_LAST] = {0};
STATIC uint8_t u8NofSettings = 3;
STATIC const uint32_t TOGGLE_INTERVAL_MS = 200;
STATIC uint8_t u8CurrentSetting = 0;
STATIC int32_t s32EncoderValue = 0;
STATIC InternalState_t sInternalState = {0};
STATIC timer_t sAnimationTimer = {0};

/********************************************************
 * Private Function Prototypes
 ********************************************************/

void Settings_getMinuteArray(const TimeCfg_s *const in_psTimeCfg, uint8_t *const out_pu8MinuteArray);

uint8_t Settings_getCurrentSettingFromEncoder(int32_t s32CurrentEncoderValue);

/********************************************************
 * FSM
 ********************************************************/

// State Definiton
typedef enum
{
    SETTING_STATE_IDLE = 0U,
    SETTING_STATE_INIT,
    SETTING_STATE_SELECT_SETTING,
    SETTING_STATE_CLEAN_UP,
    SETTING_STATE_LAST
} Settings_State_e;

// Event Defintion
typedef enum
{
    SETTING_EVENT_TRIGGERED = 0U,
    SETTING_EVENT_INIT_COMPLETE,
    SETTING_EVENT_SETTING_SELECTED,
    SETTING_EVENT_SETTING_CLEANED_UP,
    SETTING_EVENT_LAST
} Settings_Event_e;

// Function Prototypes for the State Functions
STATIC void Settings_IdleStateFunction(void);
STATIC void Settings_InitStateFunction(void);
STATIC void Settings_SelectSettingStateFunction(void);
STATIC void Settings_CleanUpStateFunction(void);

// Map State functions to States
STATIC const FSM_StateActionCb aStateActions[] = {
    [SETTING_STATE_IDLE] = Settings_IdleStateFunction,
    [SETTING_STATE_INIT] = Settings_InitStateFunction,
    [SETTING_STATE_SELECT_SETTING] = Settings_SelectSettingStateFunction,
    [SETTING_STATE_CLEAN_UP] = Settings_CleanUpStateFunction,
};

// Transition Matrix
STATIC const uint16_t Settings_transitionMatrix[SETTING_STATE_LAST][SETTING_EVENT_LAST] = {
    [SETTING_STATE_IDLE] = {
        [SETTING_EVENT_TRIGGERED] = SETTING_STATE_INIT,
        [SETTING_EVENT_INIT_COMPLETE] = SETTING_STATE_IDLE,
        [SETTING_EVENT_SETTING_SELECTED] = SETTING_STATE_IDLE,
        [SETTING_EVENT_SETTING_CLEANED_UP] = SETTING_STATE_IDLE,
    },
    [SETTING_STATE_INIT] = {
        [SETTING_EVENT_TRIGGERED] = SETTING_STATE_INIT,
        [SETTING_EVENT_INIT_COMPLETE] = SETTING_STATE_SELECT_SETTING,
        [SETTING_EVENT_SETTING_SELECTED] = SETTING_STATE_INIT,
        [SETTING_EVENT_SETTING_CLEANED_UP] = SETTING_STATE_INIT,
    },
    [SETTING_STATE_SELECT_SETTING] = {
        [SETTING_EVENT_TRIGGERED] = SETTING_STATE_SELECT_SETTING,
        [SETTING_EVENT_INIT_COMPLETE] = SETTING_STATE_SELECT_SETTING,
        [SETTING_EVENT_SETTING_SELECTED] = SETTING_STATE_CLEAN_UP,
        [SETTING_EVENT_SETTING_CLEANED_UP] = SETTING_STATE_SELECT_SETTING,
    },
    [SETTING_STATE_CLEAN_UP] = {
        [SETTING_EVENT_TRIGGERED] = SETTING_STATE_CLEAN_UP,
        [SETTING_EVENT_INIT_COMPLETE] = SETTING_STATE_CLEAN_UP,
        [SETTING_EVENT_SETTING_SELECTED] = SETTING_STATE_CLEAN_UP,
        [SETTING_EVENT_SETTING_CLEANED_UP] = SETTING_STATE_IDLE,
    }};

// Generate the FSM Configuration
STATIC FSM_Config_t sSettingsFsmConfig = {
    .NUMBER_OF_STATES = SETTING_STATE_LAST,
    .NUMBER_OF_EVENTS = SETTING_EVENT_LAST,
    .au16TransitionMatrix = (const uint16_t *)Settings_transitionMatrix,
    .asStateActions = (const FSM_StateActionCb *)aStateActions,
    .u16CurrentState = SETTING_STATE_IDLE,
    .u16CurrentEvent = SETTING_EVENT_SETTING_CLEANED_UP,
};

// State Functions Implementation
void Settings_IdleStateFunction(void)
{
    // Do nothing, but wait - This state is changed from the MessageCallback function
}
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

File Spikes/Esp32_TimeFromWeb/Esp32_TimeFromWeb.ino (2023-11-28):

#include <GxEPD.h>
#include <GxDEPG0213BN/GxDEPG0213BN.h>  // 2.13" b/w 128x250, SSD1680, TTGO T5 V2.4.1, V2.3.1

// FreeFonts from Adafruit_GFX
#include <Fonts/FreeMonoBold9pt7b.h>
#include <Fonts/FreeMonoBold12pt7b.h>
#include <Fonts/FreeMonoBold18pt7b.h>
#include <Fonts/FreeMonoBold24pt7b.h>

#include <GxIO/GxIO_SPI/GxIO_SPI.h>
#include <GxIO/GxIO.h>

GxIO_Class io(SPI, /*CS=5*/ SS, /*DC=*/17, /*RST=*/16);  // arbitrary selection of 17, 16
GxEPD_Class display(io, /*RST=*/16, /*BUSY=*/4);         // arbitrary selection of (16), 4

#include <WiFi.h>
#include "time.h"

const char* ssid = "MEO-DD61C0";
const char* password = "3b2eb46012";

const char* ntpServer = "pool.ntp.org";
const long gmtOffset_sec = 0;
const int daylightOffset_sec = 3600;

struct tm printLocalTime() {
  struct tm timeinfo;
  if (!getLocalTime(&timeinfo)) {
    Serial.println("Failed to obtain time");
  }
  return timeinfo;
}

void printStringToScreen(char* string) {
  display.setRotation(1);
  display.setFont(&FreeMonoBold24pt7b);
  display.setTextColor(GxEPD_BLACK);
  int16_t tbx, tby;
  uint16_t tbw, tbh;
  display.getTextBounds(string, 0, 0, &tbx, &tby, &tbw, &tbh);

  uint16_t x = ((display.width() - tbw) / 2) - tbx;
  uint16_t y = ((display.height() - tbh) / 2) - tby;

  display.fillScreen(GxEPD_WHITE);
  display.setCursor(x, y);
  display.print(string);
  display.update();
}

void setup() {
  Serial.begin(115200);

  /*
  Wifi
  */
  Serial.printf("Connecting to %s ", ssid);
  WiFi.begin(ssid, password);
  while (WiFi.status() != WL_CONNECTED) {
    delay(500);
    Serial.print(".");
  }
  Serial.println(" CONNECTED");

  //init and get the time
  configTime(gmtOffset_sec, daylightOffset_sec, ntpServer);
  printLocalTime();

  //disconnect WiFi as it's no longer needed
  WiFi.disconnect(true);
  WiFi.mode(WIFI_OFF);

  /*
  Display
  */
  display.init(115200);  // enable diagnostic output on Serial
}

int oldMinute = 1000;
char buffer[100];

void loop() {
  struct tm timeinfo = printLocalTime();
  Serial.println(&timeinfo, "%A, %B %d %Y %H:%M:%S");

  int hour = timeinfo.tm_hour;
  int min = timeinfo.tm_min;

  if (min != oldMinute) {
    oldMinute = min;
    if (min < 10)
    {
      snprintf(buffer, 100, "%d:0%d", hour, min);
    } else {
      snprintf(buffer, 100, "%d:%d", hour, min);
    }
    printStringToScreen(buffer);
  }
  delay(1000);
  // display.powerDown();
};

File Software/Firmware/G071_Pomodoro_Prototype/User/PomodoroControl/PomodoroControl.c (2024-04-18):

#include "PomodoroControl.h"
#include "Common.h"
#include "CountdownTimer.h"
#include "FSM.h"
#include "LightEffects.h"
#include "LightEffects_Pomodoro.h"
#include "MessageBroker.h"
#include "MessageDefinitions.h"
#include "PomodoroControl_Datatypes.h"
#include "RgbLed.h"
#include "RgbLed_Config.h"
#include "Delay.h"

/********************************************************
 * Private Defines
 ********************************************************/

#define LEDS_PER_RING 60

#define TIMER_PERIOD_MIN 60000
#define TIMER_PERIOD_SEC 1000
#define TIMER_PERIOD_SNOOZE_MS 5000    // 5 Minute Snooze Interval (5000ms * 60 Increments = 5 Minutes)
#define TIMER_PERIOD_CANCEL_SEQ_MS 150 // (150ms * 60 Increments = 9 Seconds)
#define TIMER_PERIOD_WARNING_MS 300    // (300ms * 60 Increments = 30 Seconds)
#define TIMEOUT_PERIOD_MIN 5

/********************************************************
 * Private Variables
 ********************************************************/

STATIC timer_t sTimerWtBtHandler = {0};
STATIC timer_t sTimerWarningHandler = {0};
STATIC timer_t sTimerCancelSeqHandler = {0};
STATIC timer_t sTimerCancelSeqTimeoutHandler = {0};
STATIC timer_t sTimerSnoozeHandler = {0};

STATIC PCTRL_Progress_t sPomodoroProgress = {0};

STATIC LightControl_RingCountdown_s sRingCountdown = {0};

STATIC TestData_0004_s sPomodoroTimingCfg = {0};

STATIC PomodoroPeriodConfiguration_s sPomodoroPeriodCfg = {0};

/********************************************************
 * Private Function Prototypes
 ********************************************************/

STATIC void PomodoroControl_getMinuteArray(PCTRL_Progress_t *const inout_sSelf);
STATIC void PomodoroControl_updateSequence(PCTRL_Progress_t *const inout_sSelf);
STATIC void PomodoroControl_isWorktimeOver(PCTRL_Progress_t *const inout_sSelf, BOOL *const out_bIsWorktimeOver);
STATIC void PomodoroControl_isBreaktimeOver(PCTRL_Progress_t *const inout_sSelf, BOOL *const out_bIsBreaktimeOver);

/********************************************************
 * FSM Setup
 ********************************************************/

STATIC void StateActionIdle(void);
STATIC void StateActionWorktimeInit(void);
STATIC void StateActionWorktime(void);
STATIC void StateActionWarning(void);
STATIC void StateActionBreaktimeInit(void);
STATIC void StateActionBreaktime(void);
STATIC void StateActionCancelSequenceInit(void);
STATIC void StateActionCancelSequenceRunning(void);
STATIC void StateActionCancelSequenceHalted(void);
STATIC void StateActionSnooze(void);
STATIC void StateActionCleanUp(void);

/**
 * Old State ----(Event)-----> New State Matrix
 */
STATIC const uint16_t au16FsmTransitionMatrix[STATE_LAST][EVENT_LAST] = {
    // Current State
    [STATE_IDLE] =
        {
            // Event -----------> Next State
            [EVENT_POMODORO_SEQUENCE_START] = STATE_WORKTIME_INIT,
            [EVENT_TRIGGER_BTN_LONG_PRESS] = STATE_IDLE,
            [EVENT_TRIGGER_BTN_RELEASED] = STATE_IDLE,
            [EVENT_ENCODER_BTN_RELEASED] = STATE_IDLE,
            [EVENT_SEQUENCE_COMPLETE] = STATE_IDLE,
            [EVENT_SEQUENCE_PENDING] = STATE_IDLE,
        },
    // Current State
    [STATE_WORKTIME_INIT] =
        {
            // Event -----------> Next State
            [EVENT_POMODORO_SEQUENCE_START] = STATE_WORKTIME_INIT,
            [EVENT_TRIGGER_BTN_LONG_PRESS] = STATE_IDLE,
            [EVENT_TRIGGER_BTN_RELEASED] = STATE_WORKTIME_INIT,
            [EVENT_ENCODER_BTN_RELEASED] = STATE_WORKTIME_INIT,
            [EVENT_SEQUENCE_COMPLETE] = STATE_WORKTIME,
            [EVENT_SEQUENCE_PENDING] = STATE_WORKTIME_INIT,
        },
    // Current State
    [STATE_WORKTIME] =
        {
            // Event -----------> Next State
            [EVENT_POMODORO_SEQUENCE_START] = STATE_WORKTIME,
            [EVENT_TRIGGER_BTN_LONG_PRESS] = STATE_CLEAN_UP,
            [EVENT_TRIGGER_BTN_RELEASED] = STATE_WORKTIME,
            [EVENT_ENCODER_BTN_RELEASED] = STATE_WORKTIME,
            [EVENT_SEQUENCE_COMPLETE] = STATE_WARNING,
            [EVENT_SEQUENCE_PENDING] = STATE_WORKTIME,
        },
    // Current State
    [STATE_WARNING] =
        {
            // Event -----------> Next State
            [EVENT_POMODORO_SEQUENCE_START] = STATE_WARNING,
            [EVENT_TRIGGER_BTN_LONG_PRESS] = STATE_CANCEL_SEQUENCE_INIT,
            [EVENT_TRIGGER_BTN_RELEASED] = STATE_WARNING,
            [EVENT_ENCODER_BTN_RELEASED] = STATE_SNOOZE,
            [EVENT_SEQUENCE_COMPLETE] = STATE_BREAKTIME_INIT,
            [EVENT_SEQUENCE_PENDING] = STATE_WARNING,
        },
    // Current State
    [STATE_BREAKTIME_INIT] =
        {
            // Event -----------> Next State
            [EVENT_POMODORO_SEQUENCE_START] = STATE_BREAKTIME_INIT,
            [EVENT_TRIGGER_BTN_LONG_PRESS] = STATE_CANCEL_SEQUENCE_INIT,
            [EVENT_TRIGGER_BTN_RELEASED] = STATE_BREAKTIME_INIT,
            [EVENT_ENCODER_BTN_RELEASED] = STATE_BREAKTIME_INIT,
            [EVENT_SEQUENCE_COMPLETE] = STATE_BREAKTIME,
            [EVENT_SEQUENCE_PENDING] = STATE_BREAKTIME_INIT,
        },
    // Current State
    [STATE_BREAKTIME] =
        {
            // Event -----------> Next State
            [EVENT_POMODORO_SEQUENCE_START] = STATE_BREAKTIME,
            [EVENT_TRIGGER_BTN_LONG_PRESS] = STATE_CANCEL_SEQUENCE_INIT,
            [EVENT_TRIGGER_BTN_RELEASED] = STATE_BREAKTIME,
            [EVENT_ENCODER_BTN_RELEASED] = STATE_SNOOZE,
            [EVENT_SEQUENCE_COMPLETE] = STATE_CLEAN_UP,
            [EVENT_SEQUENCE_PENDING] = STATE_BREAKTIME,
        },
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

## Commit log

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2023-01-28 Proper Setup of the CubeIDE and the Low Level CMSIS Drivers
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2023-02-04 Moved the SysTick Timer and the BlinkyLed Code into respective Modules, tested the setup all working
2023-02-04 Button enables, disables Blinky LED, Wrote the unit tests - passing, wrote a short test script in main for physical examination - passing
    [BlinkyLed.c, Button.c]
2023-02-08 Managed to get the button triggering an Interrupt
2023-02-12 Minor Adjustments - Tweaking of the LED Lighting patterns
2023-02-12 Added a new flow description for git usage; Added a layered architecture Draft for the current implementation of the Pomodoro Clock
2023-02-12 Added a Block Diagram for a Microcontroller centered perspective; Added a context diagram for the nominal case of the user triggering the sequence
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2023-02-18 Add a working integration test of the Button Model and the Message Broker
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2023-02-18 Created a Button-to-Led Example to verify the refactoring and the workings on the physical Hardware; Rebuilt the project structure in the CubeIDE
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2023-03-09 Got the RTC up and running. The current time and date can be set. Upon a Reset the current time is maintained. No alars will be needed
2023-03-12 Got the Button2Blinky via the original Message Broker up and running on the new Microcontroller
    [Button_Hardware.c]
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2023-04-04 Added the function to map the current minute to the pomodoro sequence; Added test code for this; Added a configuration module, to set system parameters
2023-04-06 Refactored the Button Module, Refactored the RealTimeClock Module, Added some draft functionality to the LightControl Module, however this module in particular requires first of all a proper design -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
    [Button.c]
2023-04-07 Added a StopWatch Module, which triggers once per second, Attached the RealTimeClock to the Message Broker
    [RealTimeClock_Hardware.c]
2023-04-07 added the button to the Message Broker
    [Button.c]
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2023-04-26 Added a couple of helper functions: scaling array, calculating the score array, concatenating arrays (for the final LED Array output)
2023-04-27 added a create and publish led array function for the LightEffects Modules
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2023-04-30 Added data conversion pipeline to translate the colors -> RgbColors -> BIT encoded Information for the PWM signal
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2023-11-30 Folder Migration of the RgbLed and working on Nucleo Board, further tidying up
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2023-12-07 Refactor code and fix timer issue
    [RgbLed.c]
2023-12-09 Refactor button and LED functionality
    Update LightEffects_DotAroundTheCircle function to use a predefined effect array for LED colors
    Add LightEffects_ClearAllRingLeds function to clear all LEDs in the ring
    Update RgbLed_HardwareTest_DrawSpinningCircle function to use a predefined effect array for LED colors
    Update StandbyControl_SeekingAttentionStateCb function to reduce the period per increment for LightEffects_DotAroundTheCircle
    Update StandbyControl_IdleStateCb function to remove unnecessary log statements
    Update StandbyControl_init function to clear all LEDs at initialization
    Update StandbyControl_execute function to remove unnecessary log statements
    Fixed major bug with with sta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
    [Button.c, RgbLed.c]
2023-12-10 Added Real Time Clock Implementation and added it into the Message Broker Messaging system
    [G071_Pomodoro_Prototype.ioc, RealTimeClock_Hardware.c, main.h]
2023-12-13 Minor refactoring, Small Bug Fix, Finished Unit Tests for the State Machine
    [PomodoroControl.c]
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2024-01-01 Major Refactoring - moved the prototyped functions into the LightEffects Module- tests are passing, Added a new state to the Pomodoro State Machine for initializing the CancelSequence
2024-01-05 Added a new test to enable all Leds (Just to check for off by one errors)
    [OnBoardTest.c, RgbLed.c, RgbLed_Config.h]
2024-01-05 Refactored the Message Broker, so that now messages are passed via pointers instead of copies by value
    [OnBoardTest.c, PomodoroControl.c]
2024-01-05 refactored the Message Broker (Part 2), Refactored the ASSERT MSG Makro (it now also toggles an LED), Partially refactored the RGBLED Module
    [Button.c, OnBoardTest.c, RgbLed.c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]
2024-01-08 Minor Bug Fix on the rendering of the Rings
    [OnBoardTest.c]
2024-01-08 Added an Additional Hardware Test for Updating the LEDs once per Minute; Changed the coding style
2024-01-13 Minor Bug Fix of an Off-by-one-error; Added skelleton for the Button Implementation
    [Button.c, Button_Hardware.c, G071_Pomodoro_Prototype.ioc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]
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2024-01-14 Minor Refactoring for the Message Broker Callbacks
    [OnBoardTest.c, PomodoroControl.c]
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2024-01-14 Added the 3 Button Interactions: Short Press, Long Press, Released to the Button Module and confirmed it with the HW Test
    [Button.c, G071_Pomodoro_Prototype.ioc, OnBoardTest.c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]
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2024-02-02 Major Reworks on the Rendering of the Rings and Refactoring of the LightEffects Module
    [OnBoardTest.c, PomodoroControl.c]
2024-02-08 Added a basic Readme to the repo, Minor Bugfix in the Cancel Sequence
    [PomodoroControl.c]
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2024-02-10 Added the Rotary Encoder Driver Module, Added an Onboard Test to verify the proper behaviour by logging out the values; Refactored the Tests, so that now everything related to them sits in the OnBoar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
2024-02-11 Fixed a Minor Bug: Buttons did not work during Pomodoro Test
    [OnBoardTest.c, PomodoroControl.c]
2024-02-11 Minor Bugfix for the Snooze State
    [OnBoardTest.c, PomodoroControl.c]
2024-02-12 Removed the Standby Control Module, Factored in new Prototype Messages, Removed outdated Messages, Refactored the Button Event Message
2024-02-21 Added the Seeking Attention Module, Redesigned the Architecture
    [ContextManagement.c, OnBoardTest.c]
2024-02-26 Score Module working - corresponding LightEffects still missing; Minor Refactoring
    [ContextManagement.c, Encoder.c, OnBoardTest.c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]
2024-02-27 Minor Refactoring on the Message Broker
    [OnBoardTest.c]
2024-02-27 Added initial drafts for the PCBA Schematic
    [Btns and Encoders.kicad_sch, LEDs_InnerRing.kicad_sch, LEDs_MiddleRing.kicad_sch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]
2024-02-29 Updated CubeMx File, Created Schematic for µC, layouted the LEDs on the PCB
    [Btns and Encoders.kicad_sch, LEDs_InnerRing.kicad_sch, LEDs_MiddleRing.kicad_sch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]
2024-03-01 added the accelerometer to the Schematic
    [Accelerometer.kicad_sch, LEDs_InnerRing.kicad_sch, LEDs_MiddleRing.kicad_sch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]
2024-03-01 Implemented the Rotary encoder, the buttons, the IMU, Added it to the PCB (All the space constraining elements are now placed)
    [Accelerometer.kicad_sch, Btns and Encoders.kicad_sch, LEDs_InnerRing.kicad_sch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]
2024-03-05 Finalized the schematic, First Draft of the finished Layout
    [Accelerometer.kicad_sch, Btns and Encoders.kicad_sch, LEDs_InnerRing.kicad_sch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]
2024-03-05 Rerouted the layout
    [Pomodoro_V1.kicad_pcb]
2024-03-05 Version that was ordered online
    [Accelerometer.kicad_sch, Btns and Encoders.kicad_sch, LEDs_InnerRing.kicad_sch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]
2024-04-02 Minor refactoring on the RGBLED Driver, Changed the nominalPomodoro Script a bit, Added some dimensions into Kicad
    [Microcontroller.kicad_sch, Pomodoro_V1.kicad_pcb]
2024-04-10 Added PullDown Resistor to the NRST Pin; Changed the test scripts a bit; (However they still need refactoring); Added the nominal operation to the Executer
2024-04-11 Added a new Test Message specifically for PomodoroControl; Fixed the OBT Test for the nominal Pomodoro Test
    [OnBoardTest.c, PomodoroControl.c]
2024-04-11 Removed obsolete tests; Resolved off-by-one error
    [OnBoardTest.c, PomodoroControl.c]
2024-04-13 Changed Encoder so that it only publishes the Encover value every couple of MSEC instead of thousands of entries per seconds (which is not required)
2024-04-17 Nominal Case for setting the current Pomodoro Configuration is up and running
2024-04-18 Integration into the nominal execution successful. Bug with the animation remaining
    [Button.c, ContextManagement.c, OnBoardTest.c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]
2024-04-23 Minor Bug Fix due to the introduction of the Watchdog Module
    [OnBoardTest.c]
2024-05-01 Added a new project for the ESP32 Implementation; Got the RgbLed up and running
2024-05-01 Migrated the Button Handling Code; Migrated the Message Broker; Created a Test Function for the Button; Updated the Message Broker, so that it now notifies you when a Message does not have any subscr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
2024-05-02 Added Test for the InputSampling Thread; Moved files for LightEffects and the Pomodoro (Major Refactoring incoming for these 2)
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2024-05-06 Added the first draft for the new PCBA for the PomodoroV7
    [Connectors.kicad_sch, Inputs.kicad_sch, MicroController.kicad_sch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]
2024-05-07 Verified the microcontroller Pinout; Added basic peripheral wiring; Added the USBC Wiring
    [Connectors.kicad_sch, Inputs.kicad_sch, MicroController.kicad_sch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]
2024-05-08 FW can now be flashed to an ESP32-S2 Target; Completed the Schematic
    [Inputs.kicad_sch, MicroController.kicad_sch, Pomodoro_V7.kicad_pcb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]
2024-05-08 added the selector wheel, changed the Connectors on the Trigger Button to move the assemlby closer together
    [Inputs.kicad_sch, MicroController.kicad_sch, Pomodoro_V7.kicad_pcb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]
2024-05-09 Increased the size for the Trigger Button PCB
    [Pomodoro_V7_TriggerButton.kicad_pcb]
2024-05-09 Update on the PCBA
    [Inputs.kicad_sch, MicroController.kicad_sch, Pomodoro_V7.kicad_pcb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]
2024-05-10 Completed the PCBA Design - the formal part
    [Inputs.kicad_sch, Pomodoro_V7.step, Usb&Pwr.kicad_sch]
2024-05-17 Updated the PCBA Files
    [Inputs.kicad_sch, MicroController.kicad_sch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]
